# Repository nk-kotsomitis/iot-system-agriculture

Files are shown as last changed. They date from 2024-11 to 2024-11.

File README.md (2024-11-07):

# iot-system-agriculture
*Smart Agriculture IoT System*

The Smart Agriculture IoT System is an end-to-end IoT solution designed to monitor and manage agricultural environments. This repository includes the firmware, hardware, enclosures, and server setup required to deploy the system.



*System Overview*

This system leverages a wireless sensor network in a star topology, using NRF24L01 modules operating at 2.4GHz for communication. The network comprises soil and environmental sensors that gather data and transmit it to a central gateway. The gateway serves as the primary hub, collecting sensor data and communicating with the controllers to make real-time adjustments. For data processing and storage, the gateway connects to an Ubuntu server over WiFi, using the MQTT protocol with RabbitMQ as the message broker. On the server side, InfluxDB is used for time-series data storage and visualization, allowing for easy monitoring of historical and real-time sensor data. 

The gateway is powered by an ATMEGA1284 and connects to the internet via an ESP32 module, utilizing AT commands. The sensors and controllers in the system are based on the ATMEGA328P microcontroller. The environmental sensor is optimized for low-power operation, measuring temperature and humidity with a high-precision SHT40 sensor while also monitoring battery voltage to ensure reliable performance over extended periods. Meanwhile, the soil sensor assesses soil moisture levels using a moisture probe. The controllers are designed for both low and high-power applications, managing devices through relay control. Each controller is equipped with a battery-powered real-time clock (RTC) to maintain accurate time in case of power outages. The high-power controller additionally monitors current consumption using an ACS712 sensor for enhanced energy management.

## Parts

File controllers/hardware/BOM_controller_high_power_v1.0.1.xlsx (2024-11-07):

# | Reference Designators | Quantity | MPN | Manufacturer | Part Description | Value | Package | Remark or Link
1 | U1 | 1 | ATMEGA328P-AU | Microchip Technology / Atmel | 8-bit Microcontrollers - MCU 32KB In-system Flash 20MHz 1.8V-5.5V | ATMEGA328P_TQFP | TQFP-32
2 | U3 | 1 | SPX1117M3-L-3-3/TR | Maxlinear | LDO Voltage Regulators 3.3V 0.8A Positive | 3.3V 0.8A | SOT-223-3+A4:H4
3 | U4 | 1 | HLK-PM01 | Hi-Link | AC-DC 220V to 5V 3W Step-Down Power Supply Module | 220V to 5V | Through Hole
4 | U5 | 1 | - | - | NRF24L01+ 2.4GHz Wireless RF Transceiver Module | - | Plug In Module - 2x4 2.54mm header | Customer Provided
5 | U6 | 1 | MCP79410T-I/SN | Microchip Technology | Real Time Clock I2C GP RTCC 1Kb EE 64B SRAM ID | - | SOIC-8
6 | BH1 | 1 | MY-1220-03 | MYOUNG | Coin Cell Battery Holder CR1220 SMT | - | SMD
7 | K1, K2 | 2 | G2RL-1A-E-ASI DC5 | Omron Electronics | General Purpose Relays 1 form A w/ TV3 5VDC Coil, 16A | Power Relays | Through Hole
8 | U10, U11 | 2 | ACS712ELCTR-20A-T | ALLEGRO MICROSYSTEMS | Linear Current Sensor, Hall Effect, 20A Sensing Current, SOIC-8 | 100mV/A output | SOIC-8
9 | Y1 | 1 | TAXM4M2ILFBET2T | TAE(Zhejiang Abel Elec) | ±30ppm -20℃~70℃ 49SMD 20pF 80Ω 4000000Hz HC-49S/SMD Crystals | 4 MHz | HC-49/S
10 | Y2 | 1 | JFWSH32K25A104C | SHENZHEN JINGFA ELECTRONICS | Radial Cylinder Crystal 32.768KHz ±20ppm 12.5pF 30 KOhm(Max) Radial,3x8mm | 32.768 kHz | OSC-TH Radial 3x8mm
11 | J2, J3 | 2 | PH2.0-4P | CAX | 4-Pin Low-profile PH2.0 Housing Connector | 4 Position | Through Hole
12 | LED | 1 | 204-10SUGC/S400-A5-L | Everlight Elec | Green 525nm Through Hole 3mm Light Emitting Diodes (LED) - Water Clear | 3mm Green - Clear | Through Hole
13 | LED | 1 | ERM 1-1.140 | Bivar | LED Mounting Hardware LED Mount Self Ret Universal LED Black | T-1 3/4 (5mm) | LED Mounts
14 | J5 | 1 | C65114 | BOOMELE(Boom Precision Elec) | 2 2.54mm 6 Straight Header，Breakaway P=2.54mm Pin Headers | 6 Position | Through Hole
15 | J6 | 1 | PZ254V-11-02P | XFCN | 2.54mm Straight 2 1 Header，Breakaway Through Hole,P=2.54mm Pin Headers | 2 Position | Through Hole
16 | J7, J8, J9 | 3 | WJ500V-5.08-3P | Ningbo Kangnex Elec | PCB Screw Terminal Block Connector 5.08mm Pitch 3 Poles Vertical | 3 Position | Through Hole
17 | J10 | 1 | PTF-77 | XFCN | Fuse Holder 5x20 | - | SH22,5A
18 | Q1, Q2 | 2 | MMBT2222A |  | (BJT) NPN 600mA 40V SURFACE MOUNT TRANSISTOR | NPN | SOT23-3
19 | D1, D2 | 2 | 1N4007F (M7) |  | Silicon Rectifier Diode 1A 1000V SMA | 1A 1000V | SMA / DO-214AC
20 | D3, D4 | 2 | 1N4448WS-7-F | Diodes Incorporated | Diodes - General Purpose, Power, Switching Vr/75V Io/250mA T/R | 75 V | SOD-323
21 | C1, C2, C14, C15 | 4 | 0805CG150J500NT |  | Multilayer Ceramic Capacitor MLCC 15pF ±5% 0805 SMD | 15pF | 0805
22 | C3, C4, C5, C16, C18, C20, C21, C22 | 8 | 0805B104M500NT |  | Multilayer Ceramic Capacitor MLCC 100nF ±5% 0805 SMD | 100nF | 0805
23 | C11 | 1 | CL21B225KOFNNNE |  | Multilayer Ceramic Capacitor MLCC 2.2uF X7R ±10% 16V 0805 SMD | 2.2uF | 0805
24 | C10 | 1 | CL21A475KAQNNNE |  | Multilayer Ceramic Capacitor MLCC 4.7uF X5R ±10% 25V 0805 SMD | 4.7uF | 0805
25 | C12 | 1 | GRM21BR61C106KE15L |  | X5R ±10% 16V 10uF 0805 Multilayer Ceramic Capacitors MLCC - SMD/SMT | 10uF | 0805
26 | C13 | 1 | VD1A331ME077000CE0 | Changzhou Huawei Electronics | 6.3mm 330uF 7.7mm 10V 2000hrs 105℃ ±20% -45℃~+105℃ SMD,6.3x7.7mm Aluminum Electrolytic Capacitors - SMD | 330uF | 6.3x7.7 SMD
27 | C17, C19 | 2 | CC0805KRX7R9BB102 |  | 50V 1nF X7R ±10% 0805 Multilayer Ceramic Capacitors MLCC - SMD/SMT | 1nF | 0805
28 | R1, R3, R5, R9, R14, R16 | 6 | RC0805FR-7W10KL |  | Chip Resistor - Surface Mount 10K ±1% 1/4W 0805 | 10K 1/4W | 0805
29 | R2, R4, R11, R12 | 4 | 0805W8J1001T5E |  | Chip Resistor - Surface Mount 1K ±5% 1/8W 0805 | 1K | 0805
30 | R13, R15 | 2 | 0805W8J2001T5E |  | Chip Resistor - Surface Mount 2K ±5% 1/8W 0805 | 2K | 0805
31 | R6, R7, R8, R10 | 4 | 0805W8J0472T5E |  | Chip Resistor - Surface Mount 4.7K ±5% 1/8W 0805 | 4K7 | 0805
 | Off-board components
32 | - | 1 | CMC_313_GTP | Visual Communications Company (VCC) | LED Lenses Green Diffused 5mm CMC313GTP | Green | -
33 | - | 2 | TC013-N11ASKKUGXX | Well Buying | Tactile Switches TACTILE/JOG SWITCH SPST50mA 12VDC180gf | Illuminated | -
34 | - | 2 | - |  | PH2.0 PH 2.0 4pin PH-4p connector with cable 100mm wire 24AWG | PH-4p 100mm 24AWG | -
35 | - | 1 | 0218015.MXP |  | 250V 15A Glass Tube Fuse Slow Blow,5x20mm Fuses | 15 A | -

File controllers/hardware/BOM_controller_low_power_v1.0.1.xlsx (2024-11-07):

# | Reference Designators | Quantity | MPN | Manufacturer | Part Description | Value | Package | Remark or Link
1 | U1 | 1 | ATMEGA328P-AU | Microchip Technology / Atmel | 8-bit Microcontrollers - MCU 32KB In-system Flash 20MHz 1.8V-5.5V | ATMEGA328P_TQFP | TQFP-32
2 | U3 | 1 | SPX1117M3-L-3-3/TR | Maxlinear | LDO Voltage Regulators 3.3V 0.8A Positive | 3.3 V | SOT-223-3
3 | U5 | 1 | - | - | NRF24L01+ 2.4GHz Wireless RF Transceiver Module | - | Plug In Module - 2x4 2.54mm header | Customer Provided
4 | U6 | 1 | MCP79410T-I/SN | Microchip Technology | Real Time Clock I2C GP RTCC 1Kb EE 64B SRAM ID | - | SOIC-8
5 | BH1 | 1 | MY-1220-03 | MYOUNG | Coin Cell Battery Holder CR1220 SMT | - | SMD
6 | K1, K2 | 2 | G2RL-1A-E-ASI DC5 | Omron Electronics | General Purpose Relays 1 form A w/ TV3 5VDC Coil, 16A | Power Relays | Through Hole
7 | Y1 | 1 | TAXM4M2ILFBET2T | TAE(Zhejiang Abel Elec) | ±30ppm -20℃~70℃ 49SMD 20pF 80Ω 4000000Hz HC-49S/SMD Crystals | 4 MHz | HC-49/S
8 | Y2 | 1 | JFWSH32K25A104C | SHENZHEN JINGFA ELECTRONICS | Radial Cylinder Crystal 32.768KHz ±20ppm 12.5pF 30 KOhm(Max) Radial,3x8mm | 32.768 kHz | OSC-TH Radial 3x8mm
9 | J2, J3 | 2 | PH2.0-4P | CAX | 4-Pin Low-profile PH2.0 Housing Connector | 4 Position | Through Hole
10 | LED | 1 | 204-10SUGC/S400-A5-L | Everlight Elec | Green 525nm Through Hole 3mm Light Emitting Diodes (LED) - Water Clear | 3mm Green - Clear | Through Hole
11 | LED | 1 | ERM 1-955 | Bivar | LED Mounting Hardware LED Mount Self Ret Universal LED Black | T-1 3/4 (5mm) | -
12 | J5 | 1 | C65114 | BOOMELE(Boom Precision Elec) | 2 2.54mm 6 Straight Header，Breakaway P=2.54mm Pin Headers | 6 Position | Through Hole
13 | J6 | 1 | PZ254V-11-02P | XFCN | 2.54mm Straight 2 1 Header，Breakaway Through Hole,P=2.54mm Pin Headers | 2 Position | Through Hole
14 | J7, J8 | 2 | WJ2EDGRC-5.08-4P | Ningbo Kangnex Elec | Pluggable Terminal Blocks 4Pins Pitch 5.08 Right Angle | 4 Position | Through Hole
15 | Q1, Q2 | 2 | MMBT2222A |  | (BJT) NPN 600mA 40V SURFACE MOUNT TRANSISTOR | NPN | SOT23-3
16 | D1, D2 | 2 | 1N4007F (M7) |  | Silicon Rectifier Diode 1A 1000V SMA | 50 V | SMA / DO-214AC
17 | C1, C2, C14, C15 | 4 | 0805CG150J500NT |  | Multilayer Ceramic Capacitor MLCC 15pF ±5% 0805 SMD | 15pF | 0805
18 | C3, C4, C5, C16 | 4 | 0805B104M500NT |  | Multilayer Ceramic Capacitor MLCC 100nF ±5% 0805 SMD | 100nF | 0805
19 | C11 | 1 | CL21B225KOFNNNE |  | Multilayer Ceramic Capacitor MLCC 2.2uF X7R ±10% 16V 0805 SMD | 2.2uF | 0805
20 | C10 | 1 | CL21A475KAQNNNE |  | Multilayer Ceramic Capacitor MLCC 4.7uF X5R ±10% 25V 0805 SMD | 4.7uF | 0805
21 | C12 | 1 | GRM21BR61C106KE15L |  | X5R ±10% 16V 10uF 0805 Multilayer Ceramic Capacitors MLCC - SMD/SMT | 10uF | 0805
22 | C13 | 1 | VD1A331ME077000CE0 | Changzhou Huawei Electronics | 6.3mm 330uF 7.7mm 10V 2000hrs 105℃ ±20% -45℃~+105℃ SMD,6.3x7.7mm Aluminum Electrolytic Capacitors - SMD | 330uF | 6.3x7.7 SMD
23 | R1, R3, R5, R9 | 4 | RC0805FR-7W10KL |  | Chip Resistor - Surface Mount 10K ±1% 1/4W 0805 | 10K 1/4W | 0805
24 | R2, R4, R11, R12 | 4 | 0805W8J1001T5E |  | Chip Resistor - Surface Mount 1K ±5% 1/8W 0805 | 1K | 0805
25 | R6, R7, R8, R10 | 4 | 0805W8J0472T5E |  | Chip Resistor - Surface Mount 4.7K ±5% 1/8W 0805 | 4K7 | 0805
 | Off-board components
26 | - | 1 | CMC_313_GTP | Visual Communications Company (VCC) | LED Lenses Green Diffused 5mm CMC313GTP | Green | -
27 | - | 2 | TC013-N11ASKKUGXX | Well Buying | Tactile Switches TACTILE/JOG SWITCH SPST50mA 12VDC180gf | Illuminated | -
28 | - | 2 | - |  | PH2.0 PH 2.0 4pin PH-4p connector with cable 100mm wire 24AWG | PH-4p 100mm 24AWG | -
29 |  | 2 | WJ2EDGK-5.08-4P | Ningbo Kangnex Elec | Pluggable Terminal Blocks Screw Connector 4Pins Pitch 5.08 | 4 Position | -

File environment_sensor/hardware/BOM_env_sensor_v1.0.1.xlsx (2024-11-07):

# | Reference Designators | Quantity | MPN | Manufacturer | Part Description | Value | Package | Remark or Link
1 | U1 | 1 | ATMEGA328P-AU | Microchip Technology / Atmel | 8-bit Microcontrollers - MCU 32KB In-system Flash 20MHz 1.8V-5.5V | - | TQFP-32
2 | U2 | 1 | - | NRF24L01+ 2.4GHz Wireless RF Transceiver Module | - | Plug In Module - 2x4 2.54mm header | Customer Provided
3 | U3 | 1 | SHT40-AD1B-R2 | Sensirion | Board Mount Humidity Sensors RH/ T Sensor | SHT40-AD1B-R2 | DFN-4
4 | U4 | 1 | USEQGSEAC82180 | KEMET | Air Quality Sensors Gas Detector Sensor Digital SMD CO2 | Carbon Dioxide (CO2) | SMD/SMT
5 | U5 | 1 | TCA9406DCTR | Texas Instruments | Translation - Voltage Levels Dual Bidirec 1MHz Vltg Lev-Trans | Translation - Voltage Levels | SM-8
6 | U6 | 1 | TPS60205DGSR | Texas Instruments | Switching Voltage Regulators Regulated 3.3-V Charge Pump | 3.3 V | MSOP-10
7 | Y1 | 1 | TAXM4M2ILFBET2T | TAE(Zhejiang Abel Elec) | ±30ppm -20℃~70℃ 49SMD 20pF 80Ω 4000000Hz HC-49S/SMD Crystals | 4 MHz | HC-49/S
8 | Q1, Q2 | 2 | SSM3J328R,LF | Toshiba | MOSFET P-Ch Sm Sig FET Id -6A -20V -8VGSS | P-channel | SOT-23F-3
9 | D1 | 1 | SBAT54CLT1G | ON Semiconductor | Schottky Diodes & Rectifiers SS DUAL COMMON CATHODE | Si | SOT-23
11 | J1 | 1 | PH2.0-4P | CAX | 4-Pin Low-profile PH2.0 Housing Connector | 4 Position | Through Hole
12 | J2 | 1 | C65114 | BOOMELE(Boom Precision Elec) | 2 2.54mm 6 Straight Header，Breakaway P=2.54mm Pin Headers | 6 Position | Through Hole
13 | J3 | 1 | PZ254V-11-02P | XFCN | 2.54mm Straight 2 1 Header，Breakaway Through Hole,P=2.54mm Pin Headers | 2 Position | Through Hole
14 | J4 | 1 | 2462 | Keystone Electronics | Cylindrical Battery Contacts, Clips, Holders & Springs 2 CELL AA PC HOLDER | AA 2 Battery | Through Hole
15 | J5 | 1 | ZW-02-20-F-D-800-079 | Samtec | Board to Board & Mezzanine Connectors .100" Flex Stack, Flexible Board Stacker, Custom Tail | 4 Position | Through Hole
16 | CBAT | 1 | VD1A331ME077000CE0 | Changzhou Huawei Electronics | 6.3mm 330uF 7.7mm 10V 2000hrs 105℃ ±20% -45℃~+105℃ SMD,6.3x7.7mm Aluminum Electrolytic Capacitors - SMD | 330uF | 6.3x7.7 SMD
18 | C1, C2 | 2 | 0805CG150J500NT |  | Multilayer Ceramic Capacitor MLCC 15pF ±5% 0805 SMD | 15pF | 0805
19 | C9 | 1 | TCC0805X7R224K500DT |  | 50V 220nF X7R ±10% 0805 Multilayer Ceramic Capacitors MLCC - SMD/SMT | 220nF | 0805
20 | C3, C4, C5, C6, C8, C14, C15, C17 | 8 | 0805B104M500NT |  | Multilayer Ceramic Capacitor MLCC 100nF ±5% 0805 SMD | 100nF | 0805
21 | C11, C12 | 2 | CL21B105KOFNNNE |  | Multilayer Ceramic Capacitor MLCC 1uF X7R ±10% 16V 0805 SMD | 1uF | 0805
22 | C10, C13 | 2 | CL21B225KOFNNNE |  | Multilayer Ceramic Capacitor MLCC 2.2uF X7R ±10% 16V 0805 SMD | 2.2uF | 0805
23 | C7 | 1 | GRM21BR61C106KE15L |  | X5R ±10% 16V 10uF 0805 Multilayer Ceramic Capacitors MLCC - SMD/SMT | 10uF | 0805
24 | C16 | 1 | CL21A475KAQNNNE |  | 25V 4.7uF X5R ±10% 0805 Multilayer Ceramic Capacitors MLCC - SMD/SMT | 4.7uF | 0805
25 | R1, R6, R7, R8, R9 | 5 | RC0805FR-7W10KL |  | Chip Resistor - Surface Mount 10K ±1% 1/4W 0805 | 10K 1/4W | 0805
26 | R2 | 1 | 0805W8J0105T5E |  | Chip Resistor - Surface Mount 1M ±5% 1/8W 0805 | 1M | 0805
27 | R3 | 1 | 0805W8J0474T5E |  | Chip Resistor - Surface Mount 470K ±5% 1/8W 0805 | 470K | 0805
28 | R4, R5 | 2 | 0805W8J1001T5E |  | Chip Resistor - Surface Mount 1K ±5% 1/8W 0805 | 1K | 0805
 | Off-board components
29 | - | 1 | TC013-N11ASKKUGXX | Well Buying | Tactile Switches TACTILE/JOG SWITCH SPST50mA 12VDC180gf | Illuminated | -
30 | - | 1 | - | - | PH2.0 PH 2.0 4pin PH-4p connector with cable 100mm wire 24AWG | PH-4p 100mm 24AWG | -

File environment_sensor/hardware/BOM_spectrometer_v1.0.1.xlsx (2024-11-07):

# | Reference Designators | Quantity | MPN | Manufacturer | Part Description | Value | Package
1 | U1 | 1 | AS72651-BLGT | ams | Ambient Light Sensors AS72651-BLGT LGA20 LF T&RDP | 600 nm to 870 nm | LGA-20
2 | U2 | 1 | AS72652-BLGT | ams | Ambient Light Sensors AS72652-BLGT LGA20 LF T&RDP | - | LGA-20
3 | U3 | 1 | AS72653-BLGT | ams | Ambient Light Sensors AS72653-BLGT LGA20 LF T&RDP | - | LGA-20
4 | U4 | 1 | AT25SF041B-SSHB-B | Adesto Technologies | NOR Flash 4 Mbit, 3.0V (2.7V to 3.6V), -40C to 85C, SOIC-N 150mil (Tube), Single, Dual, Quad SPI NOR flash | 4 Mbit | SOIC-8 Narrow
5 | J2 | 1 | PZ254V-12-10P | XFCN | 2 2.54mm 10 Straight Header，Breakaway Through Hole,P=2.54mm Pin Headers ROHS | 10 Position | Through Hole
6 | R1, R2 | 2 | 0805W8J0472T5E |  | Chip Resistor - Surface Mount 4.7K ±5% 1/8W 0805 | 4K7 | 0805
7 | R3, R4, R5, R6, R7 | 5 | RC0805FR-7W10KL |  | Chip Resistor - Surface Mount 10K ±1% 1/4W 0805 | 10K | 0805
8 | C1, C3, C5 | 3 | GRM21BR61C106KE15L |  | X5R ±10% 16V 10uF 0805 Multilayer Ceramic Capacitors MLCC - SMD/SMT | 10uF | 0805
9 | C2, C4, C6 | 3 | 0805B104M500NT |  | Multilayer Ceramic Capacitor MLCC 100nF ±5% 0805 SMD | 100nF | 0805
10 | C7 | 1 | UMK212B7105KG-T |  | X7R ±10% 50V 1uF 0805 Multilayer Ceramic Capacitors MLCC - SMD/SMT | 1uF | 0805

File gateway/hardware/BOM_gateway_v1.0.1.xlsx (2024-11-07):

# | Reference Designators | Quantity | MPN | Manufacturer | Part Description | Value | Package | Remark or Link
1 | U1 | 1 | ATMEGA1284-AU | Microchip Technology / Atmel | 8-bit Microcontrollers - MCU AVR 128KB FLSH 4KB EE16KB SRAM-20 MHz | - | TQFP-44
2 | U2 | 1 | SPX1117M3-L-3-3/TR | Maxlinear | LDO Voltage Regulators 3.3V 0.8A Positive | 3.3V 0.8A | SOT-223-3
3 | U4 | 1 | - | - | NRF24L01+ 2.4GHz Wireless RF Transceiver Module | - | Plug In Module - 2x4 2.54mm header | Customer Provided
4 | U5 | 1 | ESP-WROOM-02D(M1102H1600PH3Q0) | Espressif Systems | WiFi Modules (802.11) SMD Module, ESP8266EX, 16Mbits SPI flash, UART Mode, PCB antenna | - | SMD module
5 | U6 | 1 | MCP79410T-I/SN | Microchip Technology | Real Time Clock I2C GP RTCC 1Kb EE 64B SRAM ID | - | SOIC-8
6 | BH1 | 1 | MY-1220-03 | MYOUNG | Coin Cell Battery Holder CR1220 SMT | - | SMD
7 | Y1 | 1 | TXM16M0004322KBCDO00T | TAE(Zhejiang Abel Elec) | ±10ppm 16000000Hz -40℃~85℃ 18pF SMD Passive Crystal Oscillator 35Ω SMD3225-4P Crystals | 16 MHz | SMD3225-4P
8 | Y2 | 1 | JFWSH32K25A104C | SHENZHEN JINGFA ELECTRONICS | Radial Cylinder Crystal 32.768KHz ±20ppm 12.5pF 30 KOhm(Max) Radial,3x8mm | 32.768 kHz | OSC-TH Radial 3x8mm
9 | J1 | 1 | PH2.0-4P | CAX | 4-Pin Low-profile PH2.0 Housing Connector | 4 Position | Through Hole
10 | LED1, LED2, LED3 | 3 | 204-10SUGC/S400-A5-L | Everlight Elec | Green 525nm Through Hole 3mm Light Emitting Diodes (LED) - Water Clear | 3mm Green - Clear | Through Hole
11 | LED1, LED2, LED3 | 3 | ERM 1-955 | Bivar | LED Mounting Hardware LED Mount Self Ret Universal LED Black | T-1 3/4 (5mm) | - | Led Spacer
12 | J6 | 1 | C65114 | BOOMELE(Boom Precision Elec) | 2 2.54mm 6 Straight Header，Breakaway P=2.54mm Pin Headers | 6 Position | Through Hole
13 | J7 | 1 | PZ254V-11-02P | XFCN | 2.54mm Straight 2 1 Header，Breakaway Through Hole,P=2.54mm Pin Headers | 2 Position | Through Hole
14 | J8 | 1 | C49257 | BOOMELE(Boom Precision Elec) | 3 2.54mm Straight 1 Header，Breakaway Through Hole Pin Headers | 3 Position | Through Hole
15 | S2, S3 | 2 | TS-1096S-A2B2-C1D2 | Yuandi | SPST Vertical Tactile Switch 3X6X5.0mm SMT | - | SMD
16 | C15, C16 | 2 | 0805CG150J500NT |  | Multilayer Ceramic Capacitor MLCC 15pF ±5% 0805 SMD | 15pF | 0805
17 | C1, C2 | 2 | 0805CG270J500NT |  | Multilayer Ceramic Capacitor MLCC 27pF ±5% 0805 SMD | 27pF | 0805
18 | C3, C4, C5, C6, C7, C13, C14, C17 | 8 | 0805B104M500NT |  | Multilayer Ceramic Capacitor MLCC 100nF ±5% 0805 SMD | 100nF | 0805
19 | C9 | 1 | CL21B225KOFNNNE |  | Multilayer Ceramic Capacitor MLCC 2.2uF X7R ±10% 16V 0805 SMD | 2.2uF | 0805
20 | C8 | 1 | CL21A475KAQNNNE |  | Multilayer Ceramic Capacitor MLCC 4.7uF X5R ±10% 25V 0805 SMD | 4.7uF | 0805
21 | C10, C12 | 2 | GRM21BR61C106KE15L |  | X5R ±10% 16V 10uF 0805 Multilayer Ceramic Capacitors MLCC - SMD/SMT | 10uF | 0805
22 | C11 | 1 | VD1A331ME077000CE0 | Changzhou Huawei Electronics | 6.3mm 330uF 7.7mm 10V 2000hrs 105℃ ±20% -45℃~+105℃ SMD,6.3x7.7mm Aluminum Electrolytic Capacitors - SMD | 330uF | 6.3x7.7 SMD
23 | R1, R2, R11, R12, R13, R16, R17, R18 | 8 | 0805W8J1002T5E |  | Chip Resistor - Surface Mount 10K ±5% 1/8W 0805 | 10K | 0805
24 | R14 | 1 | 0805W8J1001T5E |  | Chip Resistor - Surface Mount 1K ±5% 1/8W 0805 | 1K | 0805
25 | R15 | 1 | 0805W8J2001T5E |  | Chip Resistor - Surface Mount 2K ±5% 1/8W 0805 | 2K | 0805
26 | R4, R5, R6, R7, R8, R9, R10, R19 | 8 | 0805W8J0472T5E |  | Chip Resistor - Surface Mount 4.7K ±5% 1/8W 0805 | 4K7 | 0805
 | Off-board components
27 | - | 1 | TC013-N11ASKKUGXX | Well Buying | Tactile Switches TACTILE/JOG SWITCH SPST50mA 12VDC180gf | Illuminated | -
28 | - | 3 | CMC_313_GTP | Visual Communications Company (VCC) | LED Lenses Green Diffused 5mm CMC313GTP | Green | -
29 | - | 1 | - | - | PH2.0 PH 2.0 4pin PH-4p connector with cable 100mm wire 24AWG | PH-4p 100mm 24AWG | -

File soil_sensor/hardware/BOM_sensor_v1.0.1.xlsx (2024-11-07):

# | Reference Designators | Quantity | MPN | Manufacturer | Part Description | Value | Package | Remark or Link
1 | U1 | 1 | ATMEGA328P-AU | Microchip Technology / Atmel | 8-bit Microcontrollers - MCU 32KB In-system Flash 20MHz 1.8V-5.5V | ATMEGA328P_TQFP | TQFP-32
2 | U2 | 1 | - | - | NRF24L01+ 2.4GHz Wireless RF Transceiver Module | - | Plug In Module - 2x4 2.54mm header | Customer Provided
3 | Y1 | 1 | TAXM4M2ILFBET2T | TAE(Zhejiang Abel Elec) | ±30ppm -20℃~70℃ 49SMD 20pF 80Ω 4000000Hz HC-49S/SMD Crystals | 4 MHz | HC-49/S
4 | Q1 | 1 | SSM3J328R,LF | Toshiba | MOSFET P-Ch Sm Sig FET Id -6A -20V -8VGSS |  | SOT-23F-3
5 | D1 | 1 | SBAT54CLT1G | ON Semiconductor | Schottky Diodes & Rectifiers SS DUAL COMMON CATHODE | Schottky Diodes | SOT-23
6 | D2, D3, D4, D5 | 4 | 1SS384TE85LF | 1SS384TE85LF | Schottky Diodes & Rectifiers 0.1A 10V Schottky Small Sig Diode | Schottky Diodes | SOT-343-4
7 | J1 | 1 | PH2.0-4P | CAX | 4-Pin Low-profile PH2.0 Housing Connector | 4 Position | Through Hole
8 | J2 | 1 | C65114 | BOOMELE(Boom Precision Elec) | 2 2.54mm 6 Straight Header，Breakaway P=2.54mm Pin Headers | 6 Position | Through Hole
9 | J3 | 1 | PZ254V-11-02P | XFCN | 2.54mm Straight 2 1 Header，Breakaway Through Hole,P=2.54mm Pin Headers | 2 Position | Through Hole
10 | J4 | 1 | 2462 | Keystone Electronics | Cylindrical Battery Contacts, Clips, Holders & Springs 2 CELL AA PC HOLDER | AA 2 Battery | Through Hole
11 | J5, J6, J7, J8 | 4 | STX-3120-3B | Kycon | Phone Connectors 3.5mm PCB STEREO BLK 3P ALL PLASTIC | 3.5 mm, 1/8 in | Through Hole
12 | CBAT | 1 | VD1A331ME077000CE0 | Changzhou Huawei Electronics | 6.3mm 330uF 7.7mm 10V 2000hrs 105℃ ±20% -45℃~+105℃ SMD,6.3x7.7mm Aluminum Electrolytic Capacitors - SMD | 330uF | 6.3x7.7 SMD
13 | C1, C2 | 2 | 0805CG150J500NT |  | Multilayer Ceramic Capacitor MLCC 15pF ±5% 0805 SMD | 15pF | 0805
14 | C3, C4, C5, C6 | 4 | 0805B104M500NT |  | Multilayer Ceramic Capacitor MLCC 100nF ±5% 0805 SMD | 100nF | 0805
15 | C8, C9, C10, C11 | 4 | UMK212B7105KG-T |  | X7R ±10% 50V 1uF 0805 Multilayer Ceramic Capacitors MLCC - SMD/SMT | 1uF | 0805
16 | C7 | 1 | GRM21BR61C106KE15L |  | X5R ±10% 16V 10uF 0805 Multilayer Ceramic Capacitors MLCC - SMD/SMT | 10uF | 0805
17 | R1, R6 | 2 | RC0805FR-7W10KL |  | Chip Resistor - Surface Mount 10K ±1% 1/4W 0805 | 10K 1/4W | 0805
18 | R2 | 1 | 0805W8J0105T5E |  | Chip Resistor - Surface Mount 1M ±5% 1/8W 0805 | 1M | 0805
19 | R3 | 1 | 0805W8J0474T5E |  | Chip Resistor - Surface Mount 470K ±5% 1/8W 0805 | 470K | 0805
20 | R4, R5, R7, R9, R11, R13 | 6 | 0805W8J1001T5E |  | Chip Resistor - Surface Mount 1K ±5% 1/8W 0805 | 1K | 0805
21 | R8, R10, R12, R14 | 4 | 0805W8J0564T5E |  | Chip Resistor - Surface Mount 560K ±5% 1/8W 0805 | 560K | 0805
 | Off-board components
22 | - | 4 | 172-1283 | Kobiconn | Audio Cables / Video Cables / RCA Cables 3.5 MONO PL-S/T 36" | 3.5 mm Mono Plug | -
23 | - | 1 | TC013-N11ASKKUGXX | Well Buying | Tactile Switches TACTILE/JOG SWITCH SPST50mA 12VDC180gf | Illuminated | -
24 | - | 1 | - | - | PH2.0 PH 2.0 4pin PH-4p connector with cable 100mm wire 24AWG | PH-4p 100mm 24AWG | -

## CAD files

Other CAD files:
controllers/mechanical/WP13-18-5 G_controller.dwg
environment_sensor/mechanical/PMF-12HAB_environment_sensor.dwg
gateway/mechanical/WP10-10-4 G_gateway.dwg
soil_sensor/mechanical/WP10-10-4G_soil_sensor.dwg
environment_sensor/mechanical/WP10-10-4G_environment_sensor.dwg

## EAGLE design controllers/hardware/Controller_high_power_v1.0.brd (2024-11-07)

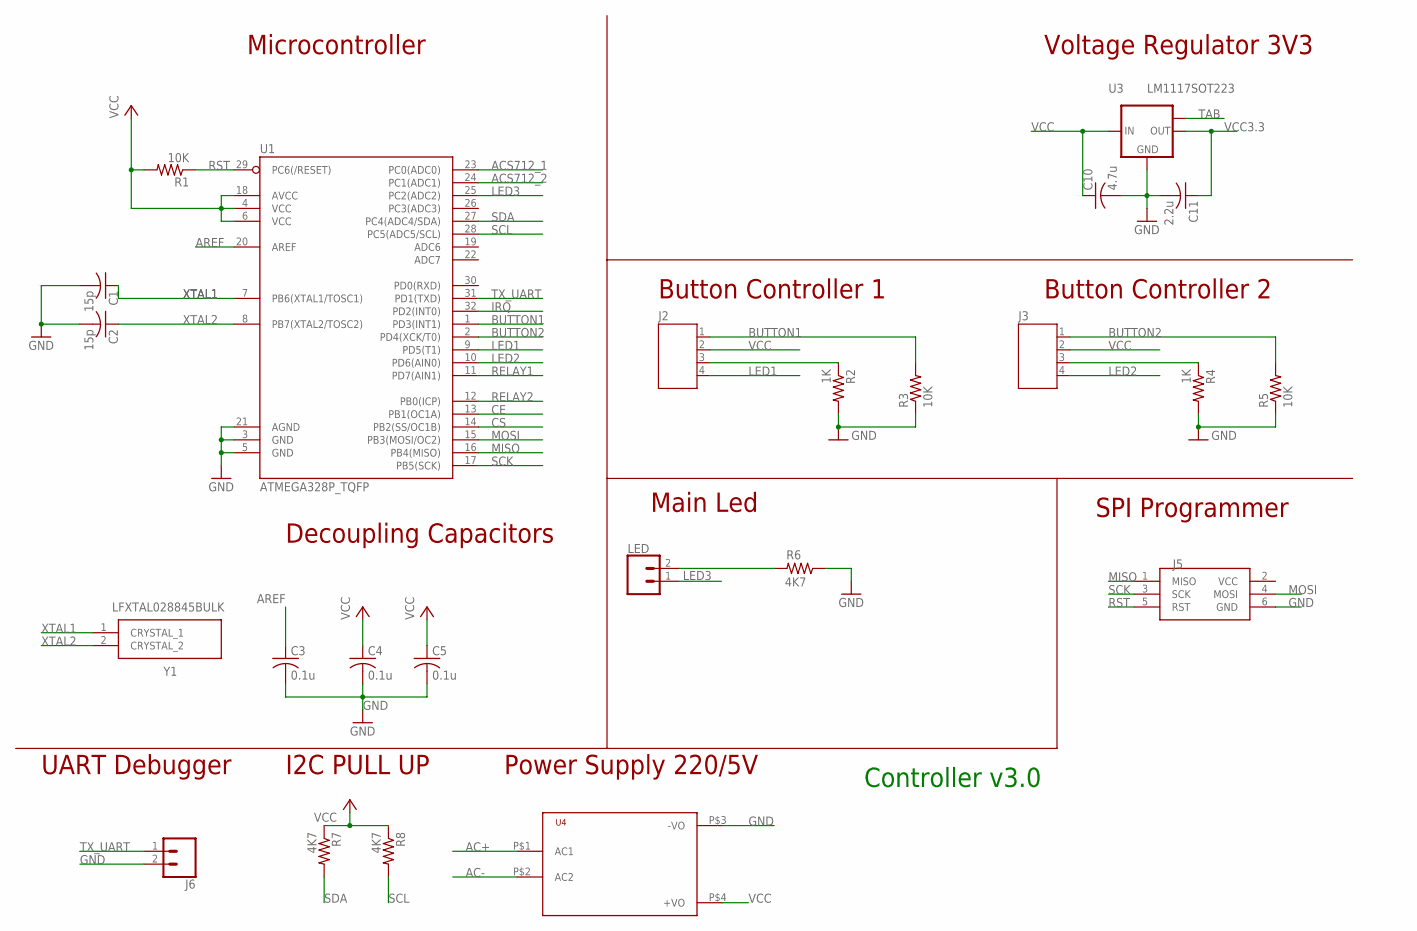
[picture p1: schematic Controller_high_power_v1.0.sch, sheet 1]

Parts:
C1, C2: 15p; SMD-0805
C3, C4, C5: 0.1u; SMD-0805
C10: 4.7u; SMD-0805
C11: 2.2u; SMD-0805
J2, J3: JST-PH4
J5: ISP; AVRISP
J6: CONN_02; 1X02
LED: CONN_02; 1X02
R1, R3, R5: 10K; SMD-0805
R2, R4: 1K; SMD-0805
R6, R7, R8: 4K7; SMD-0805
U1: ATMEGA328P_TQFP; TQFP32-08
U3: LM1117SOT223; SOT223
U4: HKLPM01
Y1: LFXTAL028845BULK

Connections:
AC+: U4.P$1 (AC1); also elsewhere on the board
AC-: U4.P$2 (AC2); also elsewhere on the board
ACS712_1: U1.23 (PC0(ADC0)); also elsewhere on the board
ACS712_2: U1.24 (PC1(ADC1)); also elsewhere on the board
AREF: C3.1, U1.20 (AREF)
BUTTON1: J2.1, R3.2, U1.1 (PD3(INT1))
BUTTON2: J3.1, R5.2, U1.2 (PD4(XCK/T0))
CE: U1.13 (PB1(OC1A)); also elsewhere on the board
CS: U1.14 (PB2(SS/OC1B)); also elsewhere on the board
GND: C1.2, C2.2, C3.2, C4.2, C5.2, C10.2, C11.2, J5.6 (GND), J6.2, R2.2, R3.1, R4.2, R5.1, R6.1, U1.3 (GND), U1.5 (GND), U1.21 (AGND), U3.1 (GND), U4.P$3 (-VO); also elsewhere on the board
IRQ: U1.32 (PD2(INT0)); also elsewhere on the board
LED1: J2.4, U1.9 (PD5(T1))
LED2: J3.4, U1.10 (PD6(AIN0))
LED3: LED.1, U1.25 (PC2(ADC2))
MISO: J5.1 (MISO), U1.16 (PB4(MISO)); also elsewhere on the board
MOSI: J5.4 (MOSI), U1.15 (PB3(MOSI/OC2)); also elsewhere on the board
unnamed: LED.2, R6.2
unnamed: J2.3, R2.1
unnamed: J3.3, R4.1
RELAY1: U1.11 (PD7(AIN1)); also elsewhere on the board
RELAY2: U1.12 (PB0(ICP)); also elsewhere on the board
RST: J5.5 (RST), R1.1, U1.29 (PC6(/RESET))
SCK: J5.3 (SCK), U1.17 (PB5(SCK)); also elsewhere on the board
SCL: R8.2, U1.28 (PC5(ADC5/SCL)); also elsewhere on the board
SDA: R7.2, U1.27 (PC4(ADC4/SDA)); also elsewhere on the board
TAB: U3.TAB (OUT1)
TX_UART: J6.1, U1.31 (PD1(TXD))
VCC: C4.1, C5.1, C10.1, J2.2, J3.2, J5.2 (VCC), R1.2, R7.1, R8.1, U1.4 (VCC), U1.6 (VCC), U1.18 (AVCC), U3.3 (IN), U4.P$4 (+VO); also elsewhere on the board
VCC3.3: C11.1, U3.2 (OUT); also elsewhere on the board
XTAL1: C1.1, U1.7 (PB6(XTAL1/TOSC1)), Y1.1 (CRYSTAL_1)
XTAL2: C2.1, U1.8 (PB7(XTAL2/TOSC2)), Y1.2 (CRYSTAL_2)

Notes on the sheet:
Controller v3.0
Decoupling Capacitors
Voltage Regulator 3V3
Microcontroller
UART Debugger
SPI Programmer
I2C PULL UP
Main Led
Button Controller 1
Power Supply 220/5V
Button Controller 2

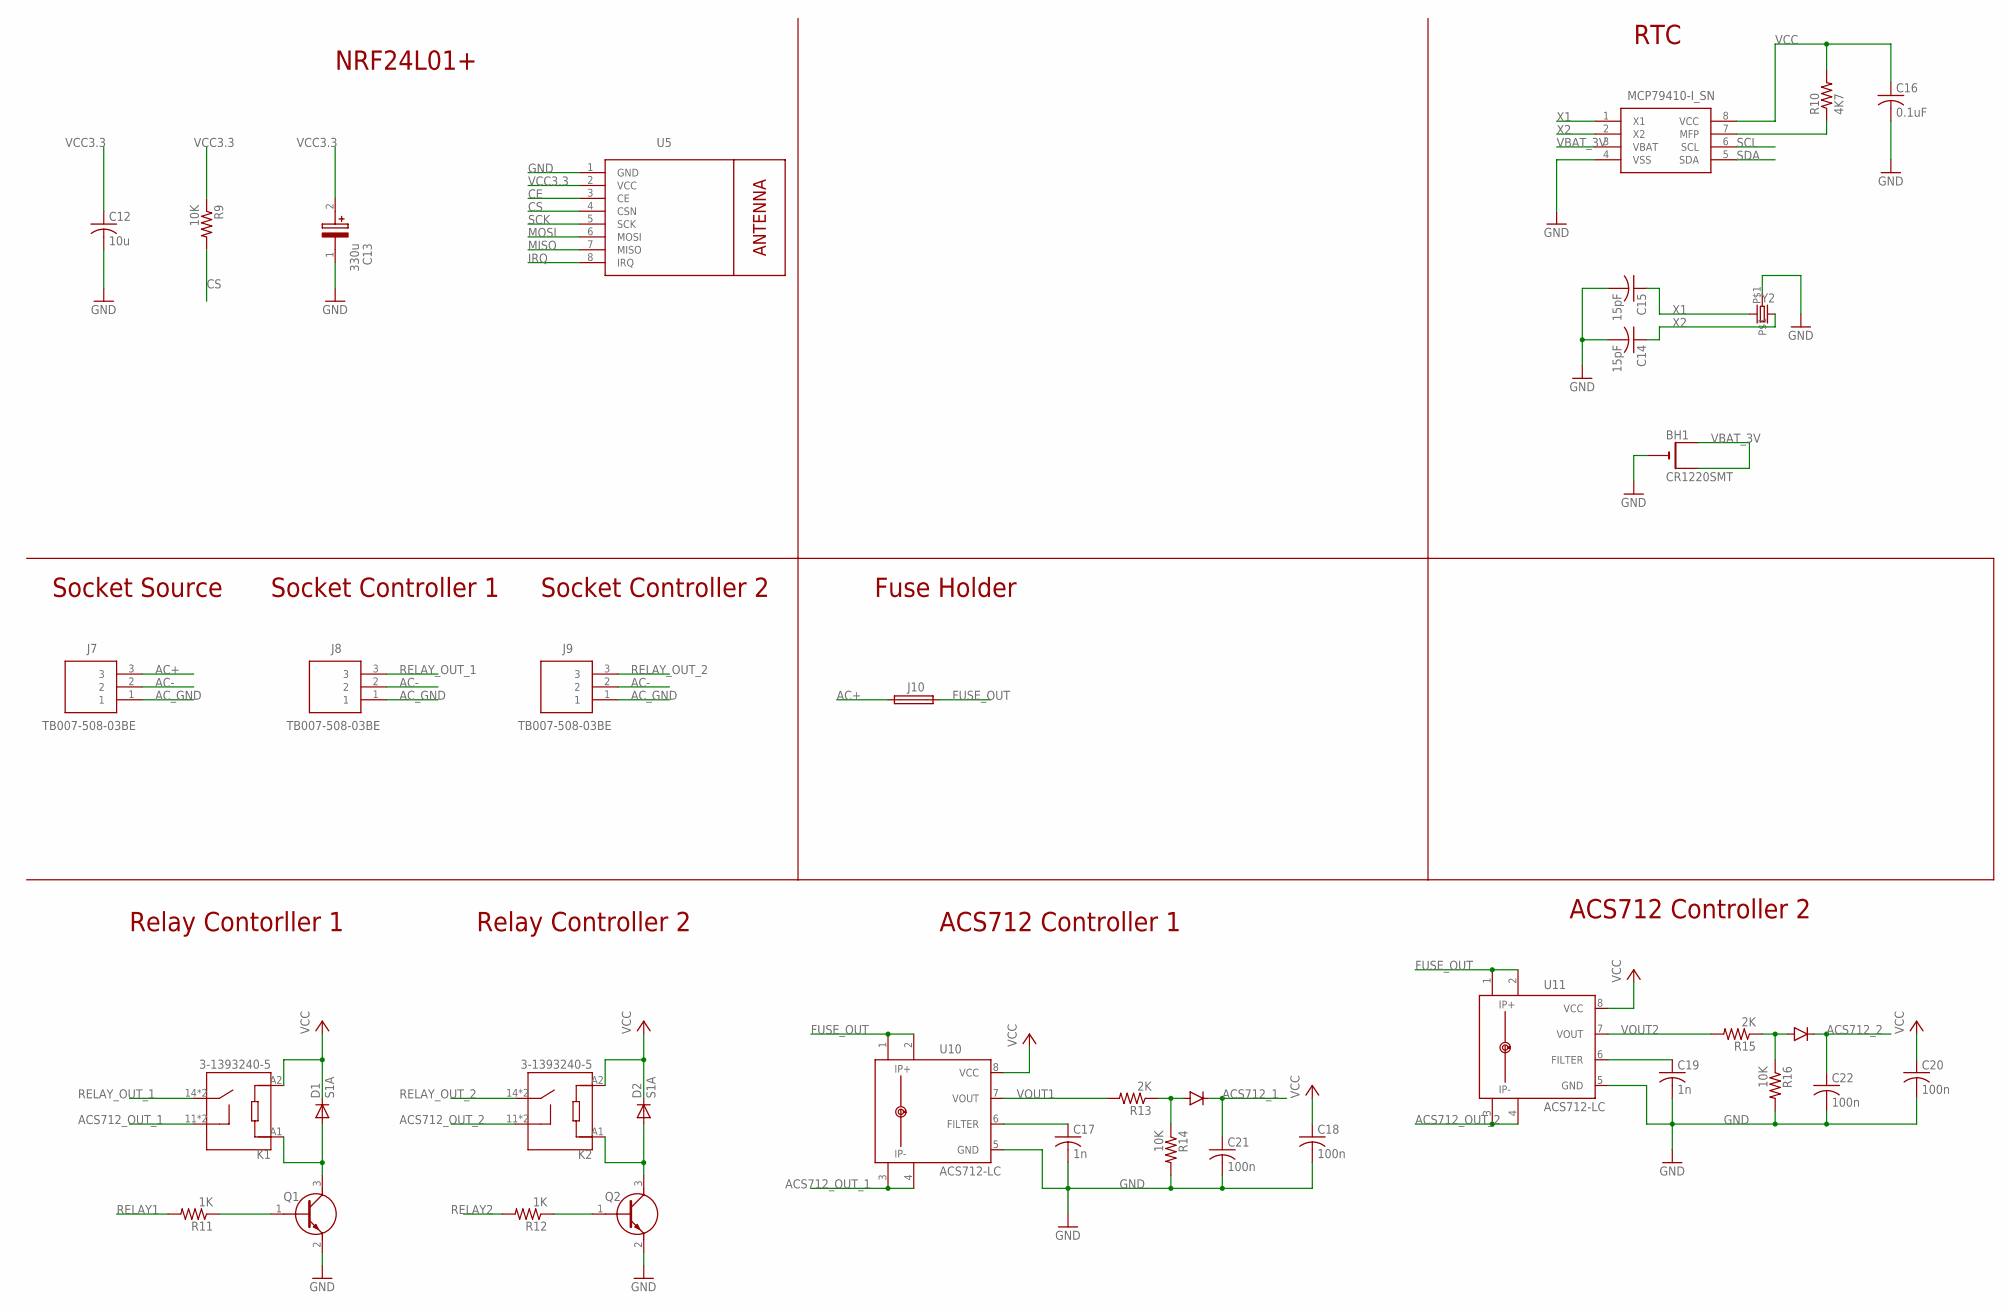
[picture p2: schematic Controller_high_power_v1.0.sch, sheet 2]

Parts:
BH1: CR1220SMT; CR1220-SMD
C12: 10u; SMD-0805
C13: 330u; SMD_LYTIC_D8
C14, C15: 15pF; SMD-0805
C16: 0.1uF; SMD-0805
C17, C19: 1n; SMD-0805
C18, C20, C21, C22: 100n; SMD-0805
D1, D2: S1A; DO214AC
D3, D4: DIODE; SOD-323
J7, J8, J9: TB007-508-03BE; TB00750803BE
J10: SH22,5A
K1, K2: 3-1393240-5; TE_3-1393240-5
Q1, Q2: MMBT2222A-TP; SI2305TP
R9, R14, R16: 10K; SMD-0805
R10: 4K7; SMD-0805
R11, R12: 1K; SMD-0805
R13, R15: 2K; SMD-0805
U5: WIRELESS-NRF24L01
U6: MCP79410-I_SN; SOIC127P600X175-8N
U10, U11: ACS712-LC; SOIC8
Y2: CRYSTALTC26H; TC26H

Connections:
AC+: J7.3, J10.1; also elsewhere on the board
AC-: J7.2, J8.2, J9.2; also elsewhere on the board
ACS712_1: C21.1, D3.C; also elsewhere on the board
ACS712_2: C22.1, D4.C; also elsewhere on the board
ACS712_OUT_1: K1.11, K1.11-1 (11), U10.3 (IP-), U10.4 (IP-1)
ACS712_OUT_2: K2.11, K2.11-1 (11), U11.3 (IP-), U11.4 (IP-1)
AC_GND: J7.1, J8.1, J9.1
CE: U5.3 (CE); also elsewhere on the board
CS: R9.2, U5.4 (CSN); also elsewhere on the board
FUSE_OUT: J10.2, U10.1 (IP+), U10.2 (IP+1), U11.1 (IP+), U11.2 (IP+1)
GND: BH1.-, C12.2, C13.1, C14.2, C15.2, C16.2, C17.2, C18.2, C19.2, C20.2, C21.2, C22.2, Q1.2 (E), Q2.2 (E), R14.2, R16.2, U5.1 (GND), U6.4 (VSS), U10.5 (GND), U11.5 (GND), Y2.P$1; also elsewhere on the board
IRQ: U5.8 (IRQ); also elsewhere on the board
MISO: U5.7 (MISO); also elsewhere on the board
MOSI: U5.6 (MOSI); also elsewhere on the board
unnamed: Q2.1 (B), R12.1
unnamed: D2.A, K2.A1, Q2.3 (C)
unnamed: D1.A, K1.A1, Q1.3 (C)
unnamed: C19.1, U11.6 (FILTER)
unnamed: C17.1, U10.6 (FILTER)
unnamed: Q1.1 (B), R11.1
unnamed: D4.A, R15.1, R16.1
unnamed: D3.A, R13.1, R14.1
unnamed: R10.1, U6.7 (MFP)
RELAY1: R11.2; also elsewhere on the board
RELAY2: R12.2; also elsewhere on the board
RELAY_OUT_1: J8.3, K1.14, K1.14-1 (14)
RELAY_OUT_2: J9.3, K2.14, K2.14-1 (14)
SCK: U5.5 (SCK); also elsewhere on the board
SCL: U6.6 (SCL); also elsewhere on the board
SDA: U6.5 (SDA); also elsewhere on the board
VBAT_3V: BH1.+$1 (+), BH1.+$2 (+1), U6.3 (VBAT)
VCC: C16.1, C18.1, C20.1, D1.C, D2.C, K1.A2, K2.A2, R10.2, U6.8 (VCC), U10.8 (VCC), U11.8 (VCC); also elsewhere on the board
VCC3.3: C12.1, C13.2, R9.1, U5.2 (VCC); also elsewhere on the board
VOUT1: R13.2, U10.7 (VOUT)
VOUT2: R15.2, U11.7 (VOUT)
X1: C15.1, U6.1 (X1), Y2.2
X2: C14.1, U6.2 (X2), Y2.1

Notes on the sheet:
NRF24L01+
Relay Contorller 1
ACS712 Controller 1
Socket Source
Fuse Holder
RTC
Relay Controller 2
Socket Controller 1
Socket Controller 2
ACS712 Controller 2

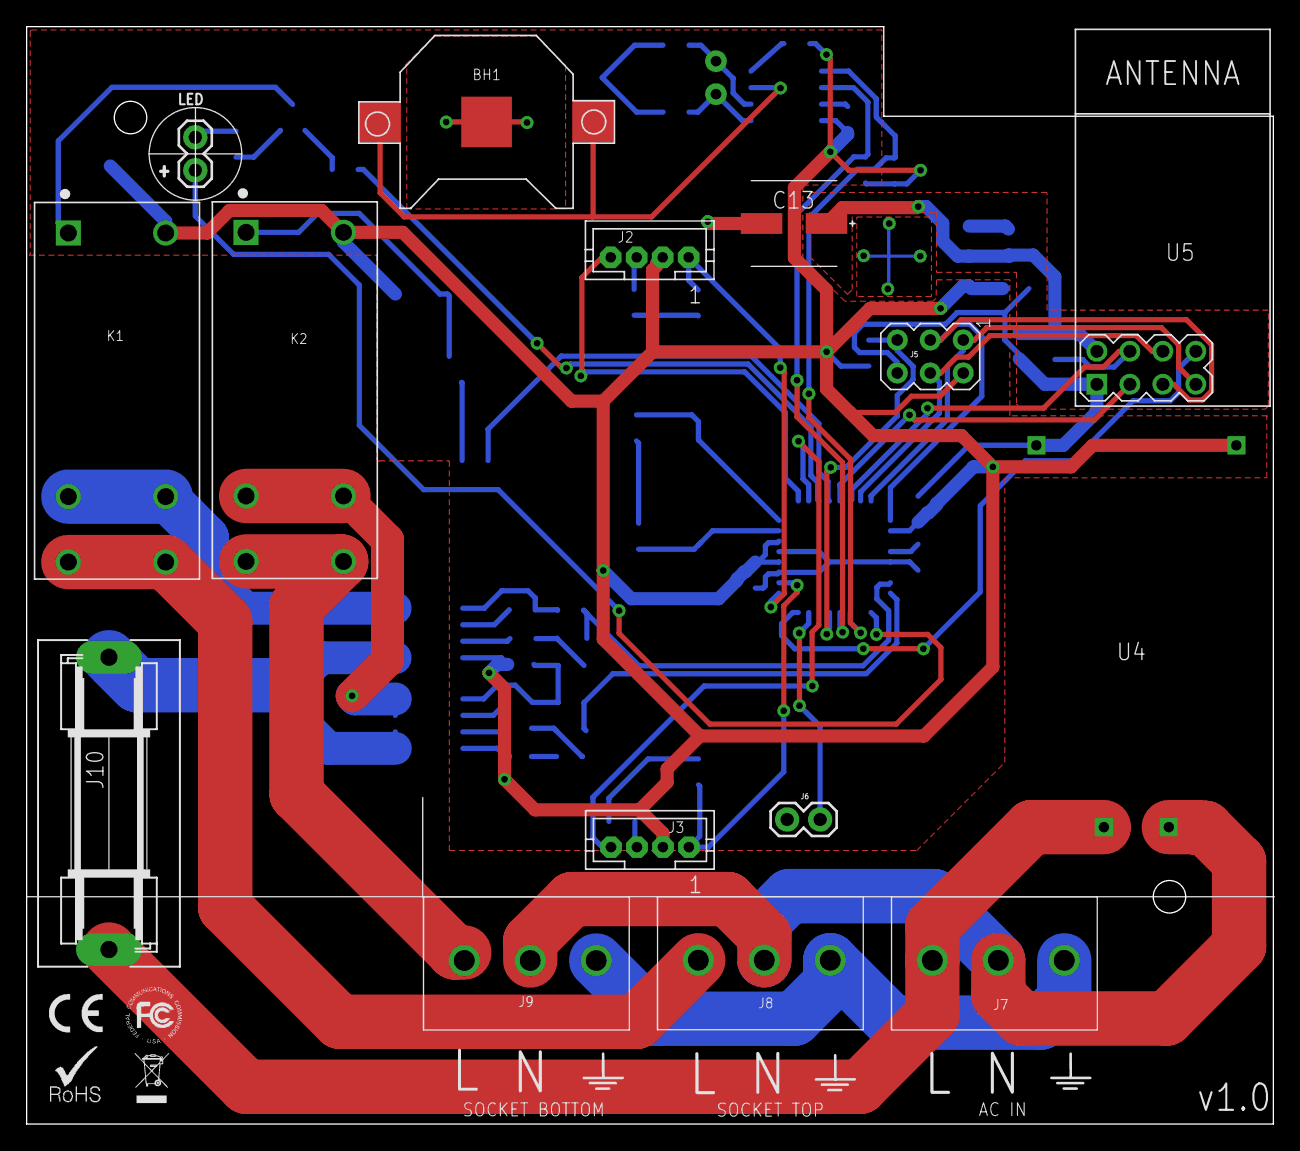
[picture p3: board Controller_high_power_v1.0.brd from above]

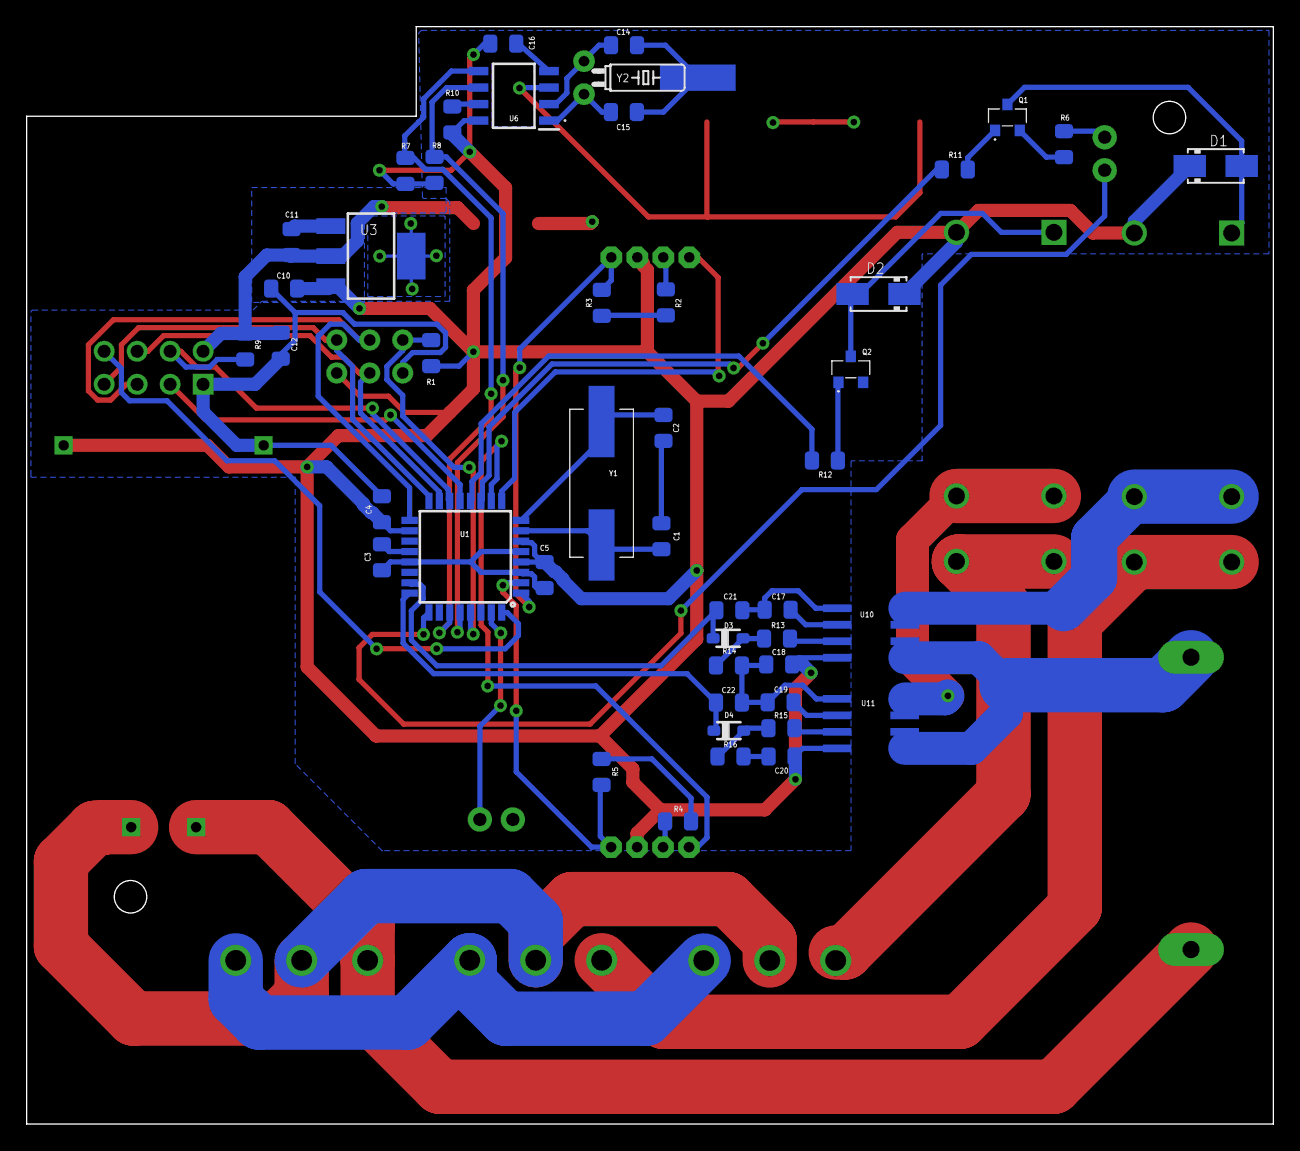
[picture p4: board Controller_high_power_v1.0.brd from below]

Board: 2 copper layers, 96.0 x 84.5 mm, 61 parts (46 on the bottom side), 50 nets.

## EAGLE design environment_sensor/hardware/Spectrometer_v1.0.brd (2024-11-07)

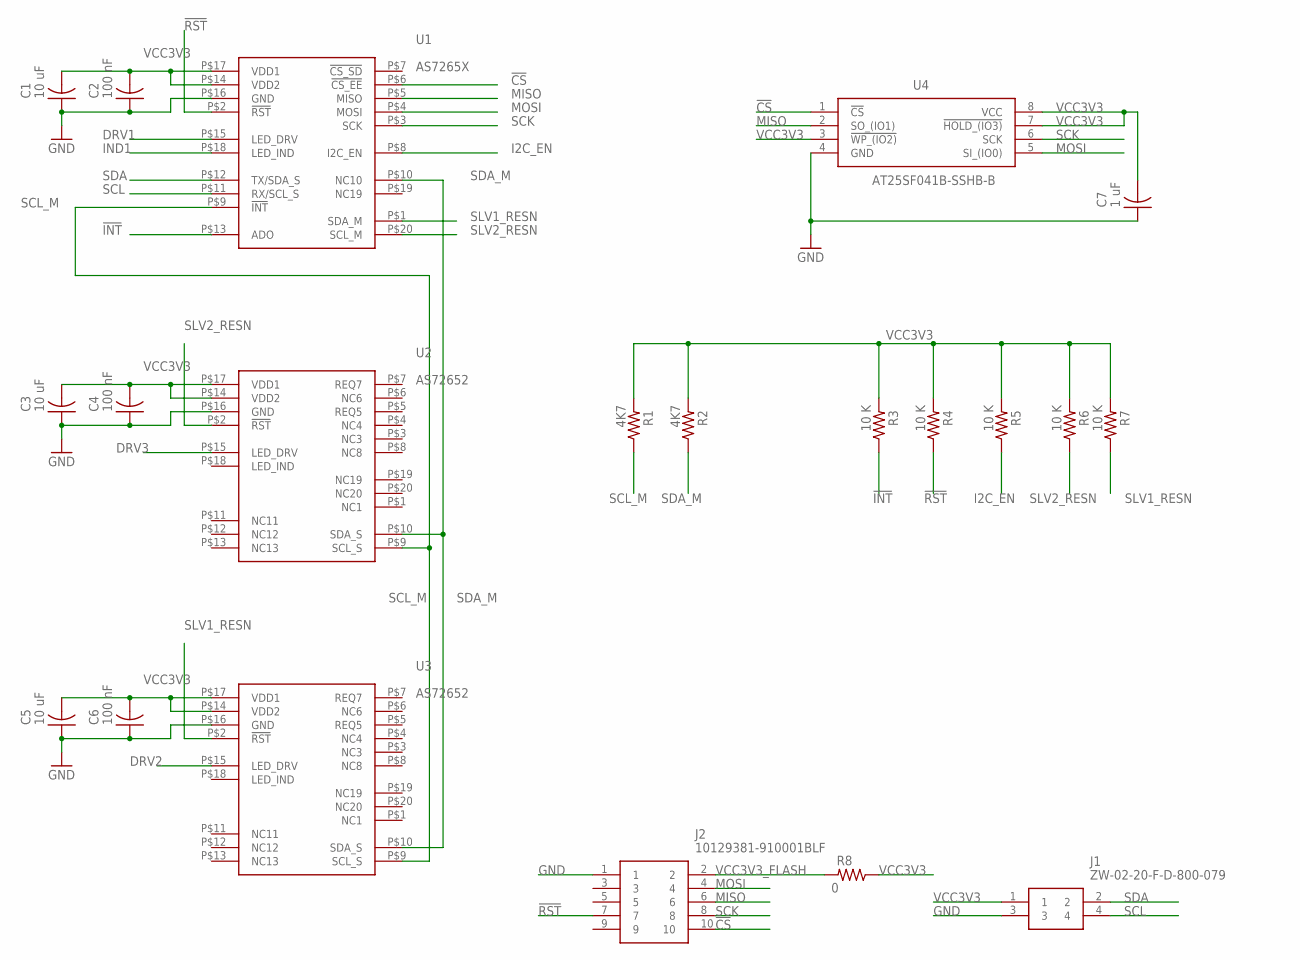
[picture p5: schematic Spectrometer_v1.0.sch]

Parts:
C1, C3, C5: 10 uF; SMD-0805
C2, C4, C6: 100 nF; SMD-0805
C7: 1 uF; SMD-0805
J1: ZW-02-20-F-D-800-079; HDRV4W64P254_2X2_508X508X2669P
J2: 10129381-910001BLF; HDRV10W67P254_2X5_1270X483X858
R1, R2: 4K7; SMD-0805
R3, R4, R5, R6, R7: 10 K; SMD-0805
R8: 0; SMD-0805
U1: AS7265X
U2, U3: AS72652; AS7265X
U4: AT25SF041B-SSHB-B; SOIC127P600X175-8N

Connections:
!CS: J2.10, U1.P$6 (!CS_EE), U4.1 (!CS)
!INT: R3.1, U1.P$13 (ADO)
!RST: J2.7, R4.1, U1.P$2 (!RST)
DRV1: U1.P$15 (LED_DRV)
DRV2: U3.P$15 (LED_DRV)
DRV3: U2.P$15 (LED_DRV)
GND: C1.1, C2.1, C3.1, C4.1, C5.1, C6.1, C7.1, J1.3, J2.1, U1.P$16 (GND), U2.P$16 (GND), U3.P$16 (GND), U4.4 (GND)
I2C_EN: R5.1, U1.P$8 (I2C_EN)
IND1: U1.P$18 (LED_IND)
MISO: J2.6, U1.P$5 (MISO), U4.2 (SO_(IO1))
MOSI: J2.4, U1.P$4 (MOSI), U4.5 (SI_(IO0))
SCK: J2.8, U1.P$3 (SCK), U4.6 (SCK)
SCL: J1.4, U1.P$11 (RX/SCL_S)
SCL_M: R1.1, U1.P$9 (!INT), U2.P$9 (SCL_S), U3.P$9 (SCL_S)
SDA: J1.2, U1.P$12 (TX/SDA_S)
SDA_M: R2.1, U1.P$10 (NC10), U2.P$10 (SDA_S), U3.P$10 (SDA_S)
SLV1_RESN: R7.1, U1.P$1 (SDA_M), U3.P$2 (!RST)
SLV2_RESN: R6.1, U1.P$20 (SCL_M), U2.P$2 (!RST)
VCC3V3: C1.2, C2.2, C3.2, C4.2, C5.2, C6.2, C7.2, J1.1, R1.2, R2.2, R3.2, R4.2, R5.2, R6.2, R7.2, R8.1, U1.P$14 (VDD2), U1.P$17 (VDD1), U2.P$14 (VDD2), U2.P$17 (VDD1), U3.P$14 (VDD2), U3.P$17 (VDD1), U4.3 (!WP_(IO2)), U4.7 (!HOLD_(IO3)), U4.8 (VCC)
VCC3V3_FLASH: J2.2, R8.2

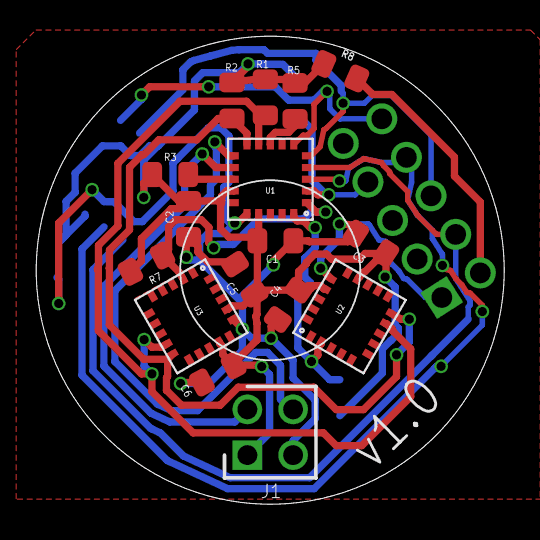
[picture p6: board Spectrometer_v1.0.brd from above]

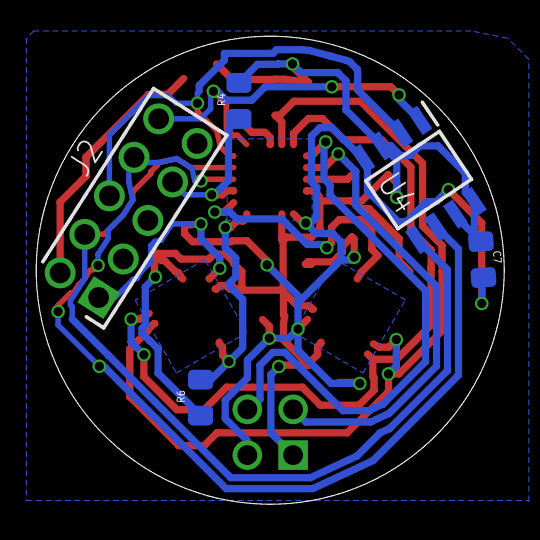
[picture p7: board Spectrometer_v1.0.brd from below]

Board: 2 copper layers, 26.0 x 26.0 mm, 21 parts (5 on the bottom side), 16 nets.

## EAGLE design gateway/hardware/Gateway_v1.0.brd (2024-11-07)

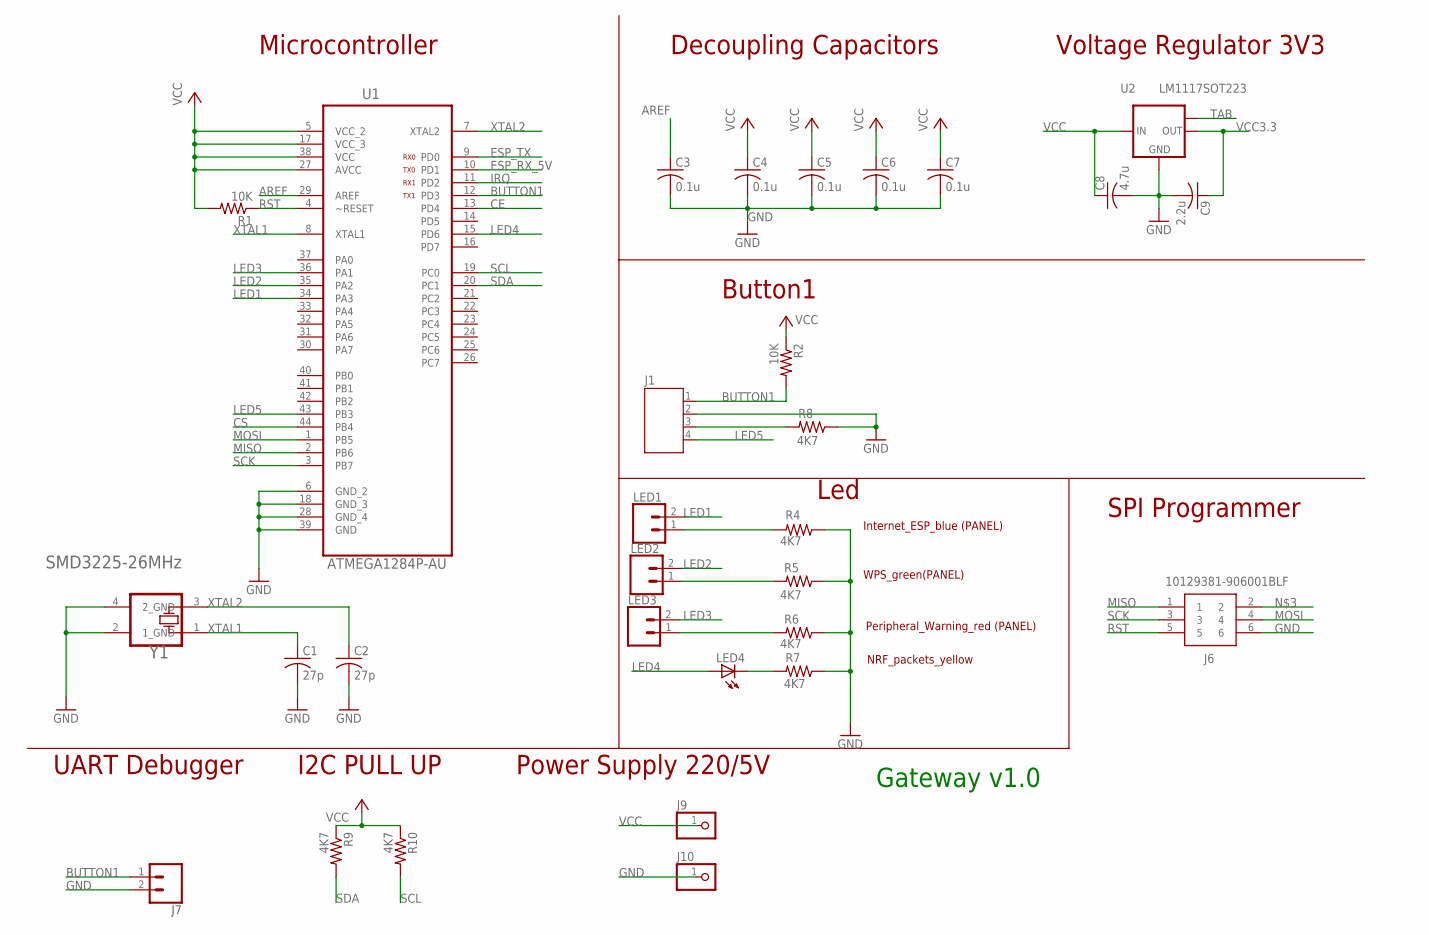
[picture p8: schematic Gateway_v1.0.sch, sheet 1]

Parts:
C1, C2: 27p; SMD-0805
C3, C4, C5, C6, C7: 0.1u; SMD-0805
C8: 4.7u; SMD-0805
C9: 2.2u; SMD-0805
J1: JST-PH4
J6: 10129381-906001BLF; HDRV6W67P254_2X3_762X483X858P
J7: CONN_02; 1X02
J9, J10: PINHD-1X1CB; 1X01-CLEANBIG
LED1, LED2, LED3: CONN_02; 1X02
LED4: LED4; SMD-0805-LED
R1, R2: 10K; SMD-0805
R4, R5, R6, R7, R8, R9, R10: 4K7; SMD-0805
U1: ATMEGA1284P-AU; QFP80P1200X1200X120-44N
U2: LM1117SOT223; SOT223
Y1: TND_ELECTRONIC_SMD3225-26MHZTND_ELECTRONIC_SMD322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; TND_ELECTRONIC_SMD3225-26MHZ_0

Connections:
AREF: C3.1, U1.29 (AREF)
BUTTON1: J1.1, J7.1, R2.2, U1.12 (PD3)
CE: U1.13 (PD4); also elsewhere on the board
CS: U1.44 (PB4); also elsewhere on the board
ESP_RX_5V: U1.10 (PD1); also elsewhere on the board
ESP_TX: U1.9 (PD0); also elsewhere on the board
GND: C1.2, C2.2, C3.2, C4.2, C5.2, C6.2, C7.2, C8.2, C9.2, J1.2, J6.6, J7.2, J10.1, R4.1, R5.1, R6.1, R7.1, R8.1, U1.6 (GND_2), U1.18 (GND_3), U1.28 (GND_4), U1.39 (GND), U2.1 (GND), Y1.2 (1_GND), Y1.4 (2_GND); also elsewhere on the board
IRQ: U1.11 (PD2); also elsewhere on the board
LED1: LED1.2, U1.34 (PA3)
LED2: LED2.2, U1.35 (PA2)
LED3: LED3.2, U1.36 (PA1)
LED4: LED4.1 (A), U1.15 (PD6)
LED5: J1.4, U1.43 (PB3)
MISO: J6.1, U1.2 (PB6); also elsewhere on the board
MOSI: J6.4, U1.1 (PB5); also elsewhere on the board
unnamed: LED2.1, R5.2
unnamed: LED3.1, R6.2
unnamed: LED1.1, R4.2
unnamed: J1.3, R8.2
unnamed: LED4.2 (C), R7.2
RST: J6.5, R1.1, U1.4 (~RESET)
SCK: J6.3, U1.3 (PB7); also elsewhere on the board
SCL: R10.2, U1.19 (PC0); also elsewhere on the board
SDA: R9.2, U1.20 (PC1); also elsewhere on the board
VCC: C4.1, C5.1, C6.1, C7.1, C8.1, J9.1, R1.2, R2.1, R9.1, R10.1, U1.5 (VCC_2), U1.17 (VCC_3), U1.27 (AVCC), U1.38 (VCC), U2.3 (IN); also elsewhere on the board
VCC3.3: C9.1, U2.2 (OUT); also elsewhere on the board
XTAL1: C1.1, U1.8 (XTAL1), Y1.1 (X1)
XTAL2: C2.1, U1.7 (XTAL2), Y1.3 (X2)
ΤΑΒ: U2.TAB (OUT1)

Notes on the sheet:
Gateway v1.0
Decoupling Capacitors
Voltage Regulator 3V3
Microcontroller
UART Debugger
SPI Programmer
I2C PULL UP
Led
Button1
TX1
RX1
Power Supply 220/5V
Internet_ESP_blue (PANEL)
NRF_packets_yellow
Peripheral_Warning_red (PANEL)
WPS_green(PANEL)
TX0
RX0

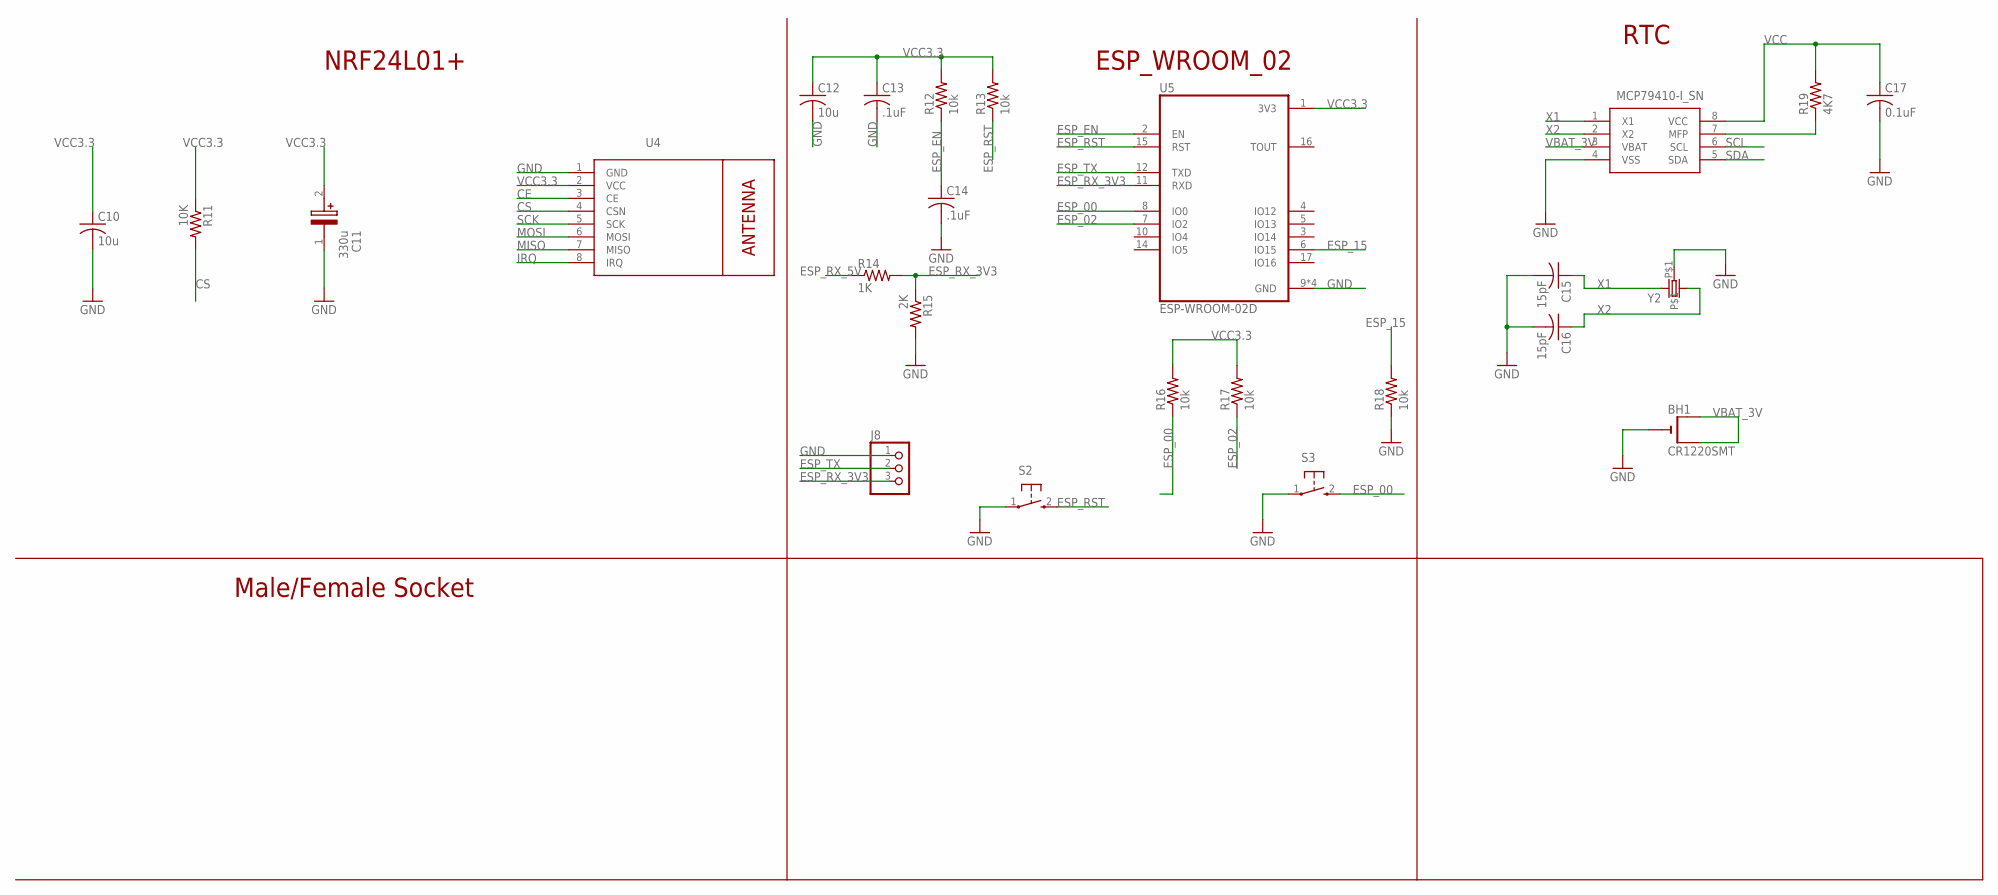
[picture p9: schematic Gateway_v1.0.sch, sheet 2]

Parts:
BH1: CR1220SMT; CR1220-SMD
C10, C12: 10u; SMD-0805
C11: 330u; SMD_LYTIC_D8
C13, C14: .1uF; SMD-0805
C15, C16: 15pF; SMD-0805
C17: 0.1uF; SMD-0805
J8: PINHD-1X3; 1X03
R11: 10K; SMD-0805
R12, R13, R16, R17, R18: 10k; SMD-0805
R14: 1K; SMD-0805
R15: 2K; SMD-0805
R19: 4K7; SMD-0805
S2, S3: SPST_TACT-KMR2; KMR2
U4: WIRELESS-NRF24L01
U5: ESP-WROOM-02D; MODULE_ESP-WROOM-02D
U6: MCP79410-I_SN; SOIC127P600X175-8N
Y2: CRYSTALTC26H; TC26H

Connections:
CE: U4.3 (CE); also elsewhere on the board
CS: R11.2, U4.4 (CSN); also elsewhere on the board
ESP_00: R16.1, S3.2 (S), U5.8 (IO0)
ESP_02: R17.1, U5.7 (IO2)
ESP_15: R18.2, U5.6 (IO15)
ESP_EN: C14.1, R12.1, U5.2 (EN)
ESP_RST: R13.1, S2.2 (S), U5.15 (RST)
ESP_RX_3V3: J8.3, R14.2, R15.1, U5.11 (RXD)
ESP_RX_5V: R14.1; also elsewhere on the board
ESP_TX: J8.2, U5.12 (TXD); also elsewhere on the board
GND: BH1.-, C10.2, C11.1, C12.2, C13.2, C14.2, C15.2, C16.2, C17.2, J8.1, R15.2, R18.1, S2.1, S3.1, U4.1 (GND), U5.9 (GND), U5.13 (GND), U5.18 (GND), U5.19 (GND), U6.4 (VSS), Y2.P$1; also elsewhere on the board
IRQ: U4.8 (IRQ); also elsewhere on the board
MISO: U4.7 (MISO); also elsewhere on the board
MOSI: U4.6 (MOSI); also elsewhere on the board
unnamed: R19.1, U6.7 (MFP)
SCK: U4.5 (SCK); also elsewhere on the board
SCL: U6.6 (SCL); also elsewhere on the board
SDA: U6.5 (SDA); also elsewhere on the board
VBAT_3V: BH1.+$1 (+), BH1.+$2 (+1), U6.3 (VBAT)
VCC: C17.1, R19.2, U6.8 (VCC); also elsewhere on the board
VCC3.3: C10.1, C11.2, C12.1, C13.1, R11.1, R12.2, R13.2, R16.2, R17.2, U4.2 (VCC), U5.1 (3V3); also elsewhere on the board
X1: C15.1, U6.1 (X1), Y2.2
X2: C16.1, U6.2 (X2), Y2.1

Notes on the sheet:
NRF24L01+
ESP_WROOM_02
Male/Female Socket
RTC

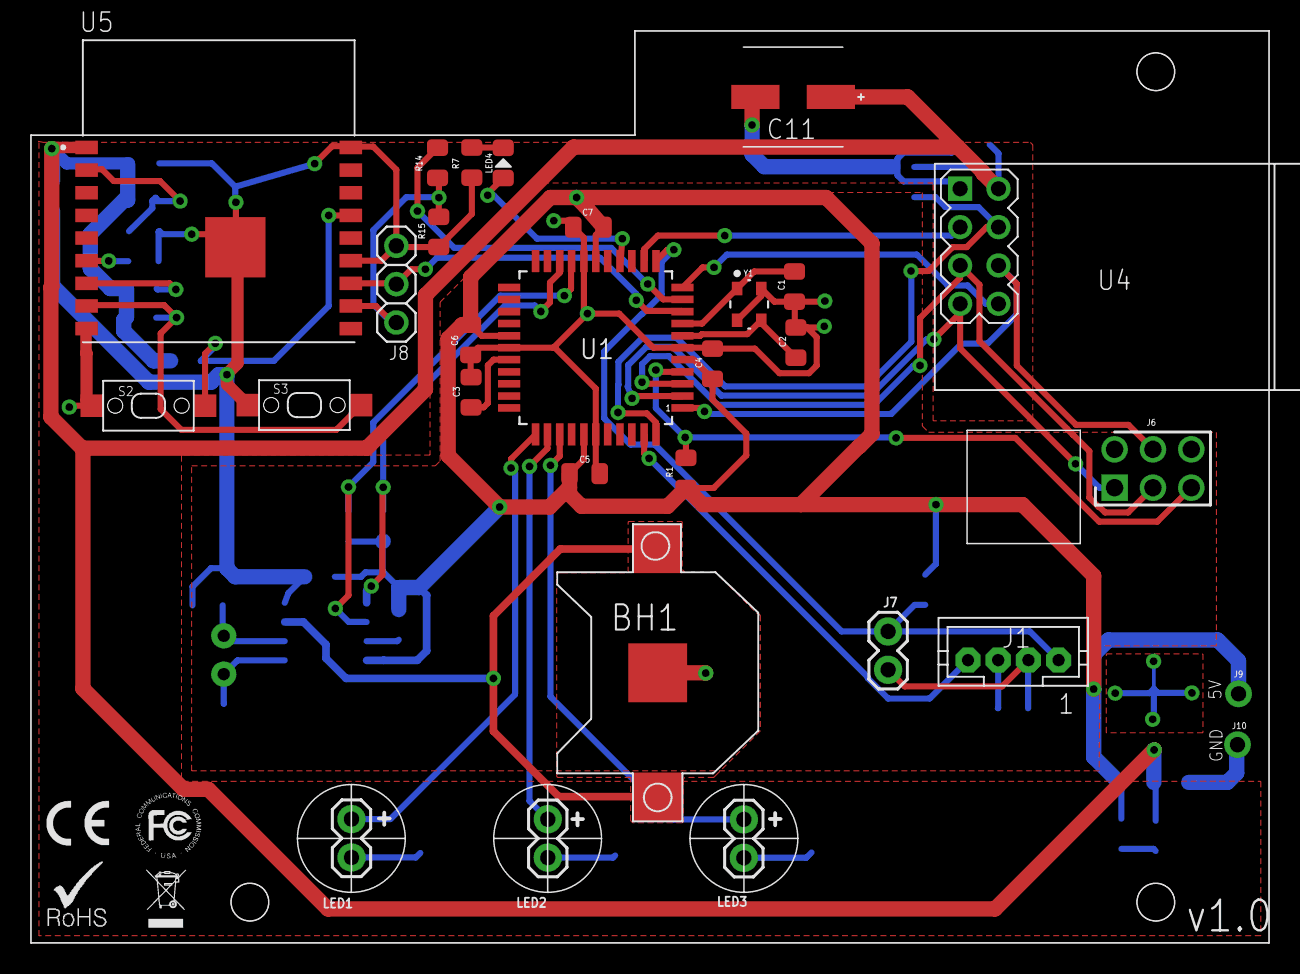
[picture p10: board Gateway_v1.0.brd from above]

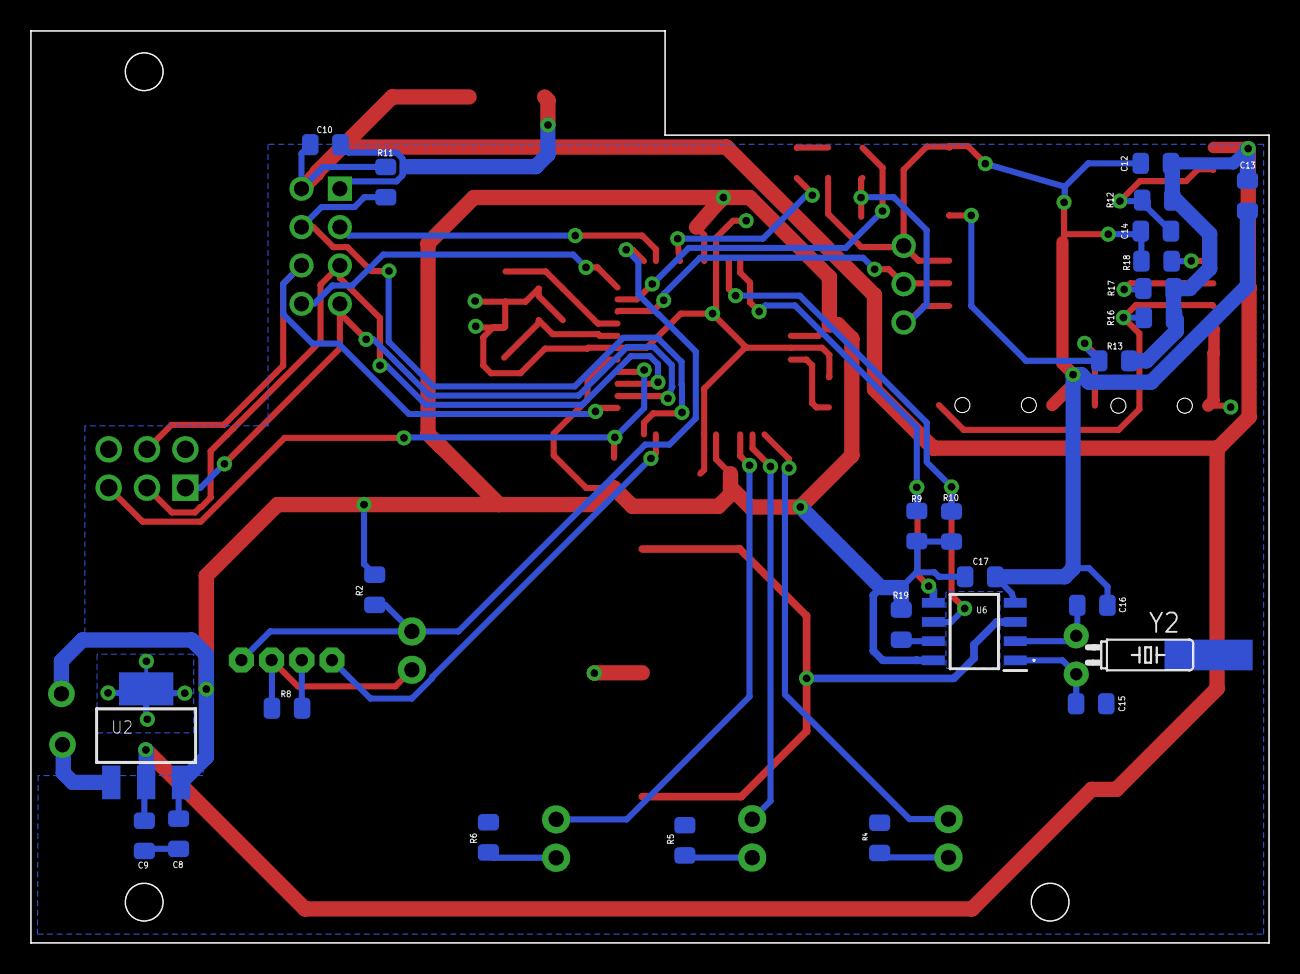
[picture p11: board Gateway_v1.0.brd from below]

Board: 2 copper layers, 82.0 x 60.4 mm, 55 parts (26 on the bottom side), 38 nets.

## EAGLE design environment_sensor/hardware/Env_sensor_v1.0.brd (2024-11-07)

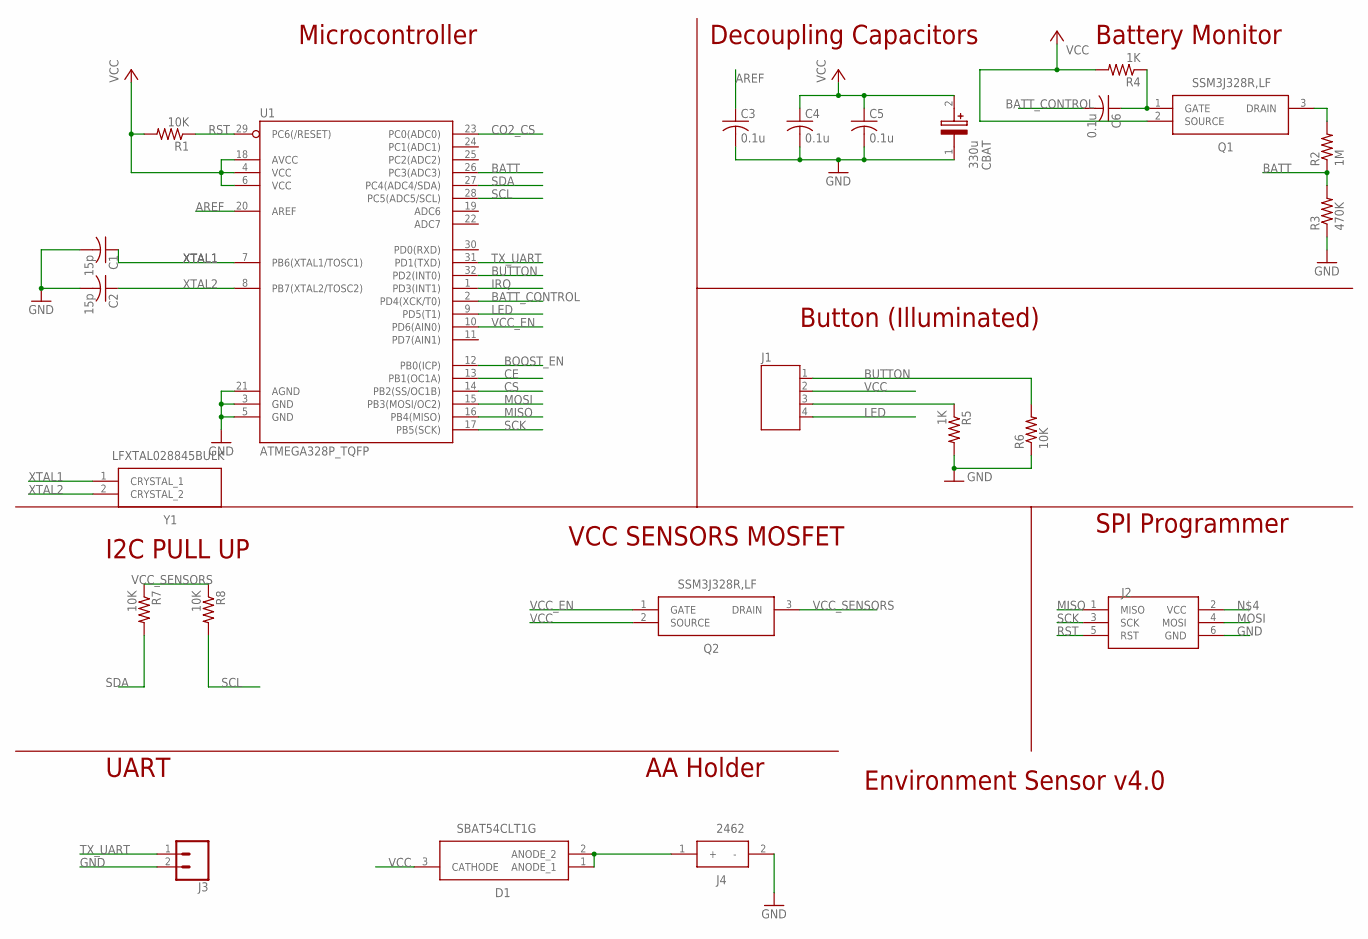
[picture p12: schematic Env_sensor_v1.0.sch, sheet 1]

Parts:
C1, C2: 15p; SMD-0805
C3, C4, C5, C6: 0.1u; SMD-0805
CBAT: 330u; SMD_LYTIC_D8
D1: SBAT54CLT1G; SOT96P237X111-3N
J1: JST-PH4
J2: ISP; AVRISP
J3: CONN_02; 1X02
J4: 2462
Q1, Q2: SSM3J328R,LF; SOTFL95P240X88-3N
R1, R6, R7, R8: 10K; SMD-0805
R2: 1M; SMD-0805
R3: 470K; SMD-0805
R4, R5: 1K; SMD-0805
U1: ATMEGA328P_TQFP; TQFP32-08
Y1: LFXTAL028845BULK

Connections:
AREF: C3.1, U1.20 (AREF)
BATT: R2.1, R3.2, U1.26 (PC3(ADC3))
BATT_CONTROL: C6.2, U1.2 (PD4(XCK/T0))
BOOST_EN: U1.12 (PB0(ICP)); also elsewhere on the board
BUTTON: J1.1, R6.2, U1.32 (PD2(INT0))
CE: U1.13 (PB1(OC1A)); also elsewhere on the board
CO2_CS: U1.23 (PC0(ADC0)); also elsewhere on the board
CS: U1.14 (PB2(SS/OC1B)); also elsewhere on the board
GND: C1.2, C2.2, C3.2, C4.2, C5.2, CBAT.1, J2.6 (GND), J3.2, J4.2 (-), R3.1, R5.2, R6.1, U1.3 (GND), U1.5 (GND), U1.21 (AGND); also elsewhere on the board
IRQ: U1.1 (PD3(INT1)); also elsewhere on the board
LED: J1.4, U1.9 (PD5(T1))
MISO: J2.1 (MISO), U1.16 (PB4(MISO)); also elsewhere on the board
MOSI: J2.4 (MOSI), U1.15 (PB3(MOSI/OC2)); also elsewhere on the board
unnamed: Q1.3 (DRAIN), R2.2
unnamed: D1.1 (ANODE_1), D1.2 (ANODE_2), J4.1 (+)
unnamed: J1.3, R5.1
unnamed: C6.1, Q1.1 (GATE), R4.1
RST: J2.5 (RST), R1.1, U1.29 (PC6(/RESET))
SCK: J2.3 (SCK), U1.17 (PB5(SCK)); also elsewhere on the board
SCL: R8.2, U1.28 (PC5(ADC5/SCL)); also elsewhere on the board
SDA: R7.2, U1.27 (PC4(ADC4/SDA)); also elsewhere on the board
TX_UART: J3.1, U1.31 (PD1(TXD))
VCC: C4.1, C5.1, CBAT.2, D1.3 (CATHODE), J1.2, Q1.2 (SOURCE), Q2.2 (SOURCE), R1.2, R4.2, U1.4 (VCC), U1.6 (VCC), U1.18 (AVCC); also elsewhere on the board
VCC_EN: Q2.1 (GATE), U1.10 (PD6(AIN0))
VCC_SENSORS: Q2.3 (DRAIN), R7.1, R8.1; also elsewhere on the board
XTAL1: C1.1, U1.7 (PB6(XTAL1/TOSC1)), Y1.1 (CRYSTAL_1)
XTAL2: C2.1, U1.8 (PB7(XTAL2/TOSC2)), Y1.2 (CRYSTAL_2)

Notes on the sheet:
Environment Sensor v4.0
Decoupling Capacitors
Battery Monitor
SPI Programmer
Microcontroller
UART
AA Holder
Button (Illuminated)
I2C PULL UP
VCC SENSORS MOSFET


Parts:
C7: 10u; SMD-0805
C8, C14, C15, C17: 0.1u; SMD-0805
C9: 0.220u; SMD-0805
C10: 2.2u; SMD-0805
C11, C12: 1uF; SMD-0805
C13: 2.2uF; SMD-0805
C16: 4.7u; SMD-0805
J5: ZW-02-20-F-D-800-079; HDRV4W64P254_2X2_508X508X2669P
R9: 10K; SMD-0805
U2: NRF24L01+; WIRELESS-NRF24L01
U3: SHT40-AD1B-R2; XDCR_SHT40-AD1B-R2
U4: USEQGSEAC82180
U5: TCA9406DCTR; SOP65P400X130-8N
U6: TPS60205; SOP50P488X107-10N

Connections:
BOOST_EN: U6.9 (EN); also elsewhere on the board
CE: U2.3 (CE); also elsewhere on the board
CO2_CS: U4.23 (CS); also elsewhere on the board
CS: R9.2, U2.4 (CSN); also elsewhere on the board
GND: C7.2, C8.2, C9.2, C10.2, C13.2, C14.2, C15.2, C16.2, C17.2, J5.3, U2.1 (GND), U3.4 (VSS), U4.5 (GND_1), U4.7 (GND_2), U4.17 (GND_3), U4.19 (GND_4), U4.28 (GND_5), U4.29 (GND_6), U4.30 (GND_7), U5.2 (GND), U6.1 (GND_1), U6.2 (GND_2); also elsewhere on the board
IRQ: U2.8 (IRQ); also elsewhere on the board
MISO: U2.7 (MISO); also elsewhere on the board
MOSI: U2.6 (MOSI); also elsewhere on the board
unnamed: C9.1, U4.3 (CAP)
unnamed: C11.1, U6.4 (C1+)
unnamed: C11.2, U6.3 (C1-)
unnamed: C12.1, U6.6 (C2+)
unnamed: C12.2, U6.8 (C2-)
SCK: U2.5 (SCK); also elsewhere on the board
SCL: U3.2 (SCL), U4.27 (SCL), U5.8 (SCL_B); also elsewhere on the board
SCL_BRD: J5.4, U5.5 (SCL_A)
SDA: U3.1 (SDA), U4.26 (SDA), U5.1 (SDA_B); also elsewhere on the board
SDA_BRD: J5.2, U5.4 (SDA_A)
VCC: C7.1, R9.1, U2.2 (VCC); also elsewhere on the board
VCC3V3: C13.1, C15.1, J5.1, U5.7 (VCCB), U6.5 (OUT)
VCC_SENSORS: C8.1, C10.1, C14.1, C16.1, C17.1, U3.3 (VDD), U4.1 (VSUPPLY), U5.3 (VCCA), U5.6 (OE), U6.7 (IN); also elsewhere on the board

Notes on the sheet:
NRF24L01+
Si7021
Spectometer
CO2
Step Up Converter 3.3V



Board: 2 copper layers, 82.3 x 60.4 mm, 42 parts (31 on the bottom side), 35 nets.

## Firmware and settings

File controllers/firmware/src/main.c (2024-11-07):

/*
* @file main.c
*
* @brief Main file
*
*/

#include "PinsAndMacros.h"

// Standard libraries
#include <string.h>
#include <stdlib.h>
#include <stdio.h>
#include <stdint.h>
#include <stdbool.h>
#include <util/delay.h>

// AVR-specific libraries
#include <avr/io.h>
#include <avr/interrupt.h>
#include <avr/wdt.h>

#include "CONSOLE_log.h"
#include "CONTROLLER_HP.h"

// Static variables
volatile static uint8_t WD_INT = 0;

// Main function
int main(void)
{
	WDT_INIT;
	HW_INIT;
	TIMERS_INIT;
		
	CONTROLLER_HP_init();
						
	while(1) 
    {
		CONTROLLER_HP_cycle_start(); 
		CONTROLLER_HP_measurements();
		CONTROLLER_HP_tasks();
		CONTROLLER_HP_connection();
		CONTROLLER_HP_cycle_end();
		wdt_reset();	
		// Cycle++
    }
}

// Watchdog Interrupt - NOT USED
ISR(WDT_vect)
{

}

// NRF24L01 IRQ pin
ISR(INT0_vect) 
{
	NRF_IRQ = 1;
}

// Interrupt 1 - NOT USED
ISR(INT1_vect) 
{

}

// Timer 0 - CTC mode 50ms - Main LED
ISR(TIMER0_COMPA_vect)	
{
	// Led state current
	static Led_state_t led_state = LED_STATE_BLINK_1S;	
	// Led state next
	Led_state_t led_state_next = g_led_state;
	
	if (g_led_flash != LED_FLASH_NONE && led_state != LED_STATE_FLASH)
	{	
		led_state = LED_STATE_FLASH;
		g_led_ticks = 0;
	}
	
	switch (led_state)
	{
		case LED_STATE_ON:
			if (led_state != led_state_next)
			{
				LED_OFF;
				led_state = led_state_next;
				g_led_ticks = 0;
				break;
			}	
			LED_ON;	
			break;
			
		case LED_STATE_OFF:
			LED_OFF;	
			led_state = led_state_next;
			break;
			
		case LED_STATE_BLINK_1S: // First OFF Then On
			g_led_ticks++;
			if (g_led_ticks >= 19)
			{
				g_led_ticks = 0;
				
				if (led_state != led_state_next)
				{
					led_state = led_state_next;
					break;
				}
				LED_TOGGLE;	
			}
			break;
			
		case LED_STATE_BLINK_500MS:
			g_led_ticks++;
			
			if (g_led_ticks >= 9)
			{
				g_led_ticks = 0;
				
				// Next state
				if (led_state != led_state_next)
				{
					led_state = led_state_next;
					break;
				}				
				LED_TOGGLE;
			}			
			break;
		
		case LED_STATE_FLASH:
			g_led_ticks++;
			LED_TOGGLE;
			
			if (g_led_ticks >= (uint16_t)g_led_flash)
			{
				g_led_ticks = 0;
				led_state = led_state_next;
				g_led_flash = LED_FLASH_NONE;
			}
			break;
		
		default:
			break;
	}
}

// Timer 2 - CTC mode 10ms - Buttons
ISR(TIMER2_COMPA_vect)
{
	uint8_t current_state = BUTTON_2_STATE;	
		
	switch (g_button_2)
	{
		case BUTTON_UNPRESSED:
			if (current_state)
			{
				g_button_2_ticks = 0;
				g_button_2 = BUTTON_IN_PROGRESS;
			}
			break;
			
		case BUTTON_IN_PROGRESS:
			g_button_2_ticks++;
				
			if (g_button_2_ticks >= BUTTON_LONG_PRESS_TICKS)
			{
				// LED blink to indicate that long press is achieved
				g_led_flash = LED_FLASH_1_SEC;
			}
				
			if (!current_state)
			{
				if (g_button_2_ticks >= BUTTON_LONG_PRESS_TICKS)
				{
						
					g_button_2 = BUTTON_LONG_PRESS;
				}
				else
				{
					g_button_2 = BUTTON_SHORT_PRESS;
				}
			}

			break;
			
		case BUTTON_SHORT_PRESS:
		case BUTTON_LONG_PRESS:
			g_button_2_ticks = 0;
			break;
			
		default:
			break;
	}		
}

/*** end of file ***/

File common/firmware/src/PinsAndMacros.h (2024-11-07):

/*
* @file PinsAndMacros.h
*
* @brief Pin and macros.
*
*/

#ifndef PINS_AND_MACROS_H
#define PINS_AND_MACROS_H

#define GETBIT(x) (1 << (x)) /* Get bit y in byte x*/
#define SETBIT(x,y) (x |= (y)) /* Set bit y in byte x*/
#define CLEARBIT(x,y) (x &= (~y)) /* Clear bit y in byte x*/
#define CHECKBIT(x,y) (x & (y)) /* Check bit y in byte x*/
#define _STRINGIZE(x) #x
#define STRINGIZE(x) _STRINGIZE(x)
	
/************************************************************************************
******************************** Gateway ********************************************
************************************************************************************/

#ifdef GATEWAY

// CPU Frequency
#define F_CPU 16000000UL

// SPI Pins for SPI library
#define SPI_PORT PORTB
#define SPI_DDR  DDRB
#define SPI_SCK  DDB7
#define SPI_MISO DDB6
#define SPI_MOSI DDB5
#define SPI_SS   DDB4

// CS and CE for NRF24L01
#define RF_CE		DDD4 // PD4
#define RF_CSN		DDB4 // PB4
#define RF_CE_INIT	DDRD |=  (1 << RF_CE);
#define RF_CS_INIT  DDRB |=  (1 << RF_CSN);
#define RF_CE_HIGH  PORTD |=  (1 << RF_CE);
#define RF_CE_LOW   PORTD &= ~(1 << RF_CE);
#define RF_CE_STATE (PORTB&GETBIT(RF_CE))
#define RF_CS_HIGH  PORTB |=  (1 << RF_CSN);
#define RF_CS_LOW   PORTB &= ~(1 << RF_CSN);

// Timers
#define TIMER_0 TCNT0
#define TIMER_1 TCNT1
#define TIMER_2 TCNT2
#define TIMER_0_TICK_MS		0.064
#define TIMER_1_TICK_MS		0.064
#define TIMER_2_TICK_MS		0.064

// Modules/Leds/Buttons
#define CONSUMPTION	0x04	// PA2
#define RELAY1		0x08	// PA3
#define NRF_CONTROL	0x20	// PD5
#define ESP_CONTROL	0x10	// PA4
#define BUTTON_1	0x04	// PB2
#define BUTTON_3	0x02	// PA1
#define LED1 0x02			// PB1
#define LED2 0x01			// PB0
#define LED3 0x01			// PA0
#define LED4 0x40 			// PD6
#define LED5 0x08			// PB3

#define consumption_init	DDRA&=~CONSUMPTION
#define relay_1_init	DDRA|=RELAY1
#define relay_1_on		PORTA|=RELAY1
#define relay_1_off		PORTA&=~RELAY1
#define relay_1_toggle	PORTA^=RELAY1
#define relay_1_read	((PORTA&RELAY1)>>3)

#define button_1_init	DDRB&=~BUTTON_1
#define button_1_pushed !(PINB&BUTTON_1)
#define button_1_pushed_seconds 3

#define led_1_init		DDRB|=LED1		// Internet
#define led_1_on		PORTB|=LED1
#define led_1_off		PORTB&=~LED1
#define led_1_toggle	PORTB^=LED1

#define led_2_init		DDRB|=LED2		// WPS
#define led_2_on		PORTB|=LED2
#define led_2_off		PORTB&=~LED2
#define led_2_toggle	PORTB^=LED2

#define led_3_init		DDRA|=LED3		// Warning
#define led_3_on		PORTA|=LED3
#define led_3_off		PORTA&=~LED3
#define led_3_toggle	PORTA^=LED3

#define led_4_init		DDRD|=LED4		// NRF packets
#define led_4_on		PORTD|=LED4
#define led_4_off		PORTD&=~LED4
#define led_4_toggle	PORTD^=LED4

#define led_5_init		DDRB|=LED5		// Relay status
#define led_5_on		PORTB|=LED5
#define led_5_off		PORTB&=~LED5
#define led_5_toggle	PORTB^=LED5


#define INTERNET_LED_ON			{TIMSK0&=(0 << OCIE0A); led_1_on;}
#define INTERNET_LED_OFF		{TIMSK0&=(0 << OCIE0A); led_1_off;}
#define INTERNET_LED_BLINK_MODE	{TIMSK0|=(1 << OCIE0A); TCNT0 = 0; INTERNET_LED_FAST }
#define INTERNET_LED_SLOW		OCR0A=157;
#define INTERNET_LED_NORMAL		OCR0A=100;
#define INTERNET_LED_FAST		OCR0A=38;
#define INTERNET_LED_SUPER_FAST	OCR0A=13;

// Tested - OK
//#define INTERNET_LED_ON			{TIMSK0&=(0 << OCIE0A); led_1_on;}
//#define INTERNET_LED_OFF		{TIMSK0&=(0 << OCIE0A); led_1_off;}
//#define INTERNET_LED_BLINK_MODE	{TIMSK0|=(1 << OCIE0A);}
//#define INTERNET_LED_SLOW		{OCR0A=157; TCNT0 = 0;}
//#define INTERNET_LED_NORMAL		{OCR0A=100; TCNT0 = 0;} // untested
//#define INTERNET_LED_FAST		{OCR0A=38; TCNT0 = 0;}
//#define INTERNET_LED_SUPER_FAST	{OCR0A=13; TCNT0 = 0;}


#define interrupt_0_init	{ EICRA |= _BV(ISC01); EIMSK |= _BV(INT0); }	// IRQ
#define interrupt_1_init	{ EICRA |= _BV(ISC11); EIMSK |= _BV(INT1); }	// Button2 - TX_debug
#define interrupt_2_init	{ EICRA |= _BV(ISC21); EIMSK |= _BV(INT2); }	// Button1

//interrupt_1_init; // Disabled because we need TX debug TODO

#define HW_INIT_GW { consumption_init; relay_1_init; button_1_init; led_1_init; led_2_init; led_3_init; led_4_init; led_5_init; interrupt_0_init; interrupt_2_init; sei(); }
	
#define WDT_INIT_GW { cli(); MCUSR &= ~(1<<WDRF); WDTCSR = (1<<WDCE)|(1<<WDE); WDTCSR = (1<<WDIE)|(0<<WDE)|(1<<WDP3)|(0<<WDP2)|(0<<WDP1|(0<<WDP0)); sei(); wdt_enable(WDTO_4S); }

/*
	Interrupts
	0 0 The low level of INTn generates an interrupt request
	0 1 Any edge of INTn generates asynchronously an interrupt request
	1 0 The falling edge of INTn generates asynchronously an interrupt request
	1 1 The rising edge of INTn generates asynchronously an interrupt request


	Watchdog 
	3|2|1|0
 	0|1|0|0		250ms
 	0|1|0|1		500ms
 	0|1|1|0		1s
 	1|0|0|0		4s
*/

#endif

/************************************************************************************
******************************** Soil Sensor ****************************************
************************************************************************************/

#ifdef SOIL_SENSOR
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

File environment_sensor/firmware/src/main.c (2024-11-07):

/*
* @file main.c
*
* @brief Main file
*
*/

#include "PinsAndMacros.h"

// Standard libraries
#include <string.h>
#include <stdlib.h>
#include <stdio.h>
#include <stdint.h>
#include <stdbool.h>
#include <util/delay.h>

// AVR-specific libraries
#include <avr/io.h>
#include <avr/sleep.h>
#include <avr/interrupt.h>
#include <avr/wdt.h>

#include "CONSOLE_log.h"
#include "ENV_SENSOR.h"

// Static variables
time_t g_time_epoch_y2k = 0;
volatile uint8_t g_wake_up = 0;

// Static functions
static void sleep(uint8_t sleep_cycles);

// Main function
int main(void)
{
	HW_INIT;  
	WDT_INIT;
	TIMERS_INIT;
	
	// Sensors ON
	VCC_EN_OFF;		// Reverse logic
	BOOST_EN_ON;
	_delay_ms(1);
	
	ENV_SENSOR_init();
	
	_delay_ms(1000);
		
	while(1) 
    {	
		ENV_SENSOR_power_up();
		ENV_SENSOR_measurements();
		ENV_SENSOR_tasks();
		ENV_SENSOR_connection();	
		ENV_SENSOR_power_down();
		
		// Connect cycles: e.g. 2 [sec] (WDT) * 5 = 10 [sec]
		sleep(SOIL_SENSOR_CONNECT_CYCLES);
    }
}

/*!
* @brief MCU sleep mode for the given number of cycles
*/
static void sleep(uint8_t sleep_cycles)
{
	g_wake_up = 0;
	
	// Set watchdog to Interrupt mode and 2 seconds
	WDT_INIT_SLEEP;
	// Set sleep power down mode
	set_sleep_mode(SLEEP_MODE_PWR_DOWN);
	cli();
	sleep_enable();
	
	for(uint8_t i = 0; i < sleep_cycles; i++)
	{
		// Enable PRR
		PRR = (PRTWI << 1) | (PRTIM2 << 1) | (PRTIM0 << 1) | (PRTIM1 << 1) | (PRSPI << 1) | (PRUSART0 << 1) | (PRADC << 1);
		// Disable BOD before sleep
		sleep_bod_disable();
		// Go to sleep
		sei();
		sleep_cpu();
		// Exit loop if button pushed
		if (g_wake_up)
		{	
			break;
		}
	}
		
	// Wake up!
	sleep_disable();
	// Disable PRR
	PRR = 0x00;
	// Set watchdog to Interrupt & System Reset mode and 2 seconds
	WDT_INIT;
}

ISR(INT0_vect)
{
	// NRF24L01 IRQ pin
	NRF_IRQ = 1;
}

ISR(INT1_vect)
{
	//LED_TOGGLE;
	
	// Used to wake up!
	// NOTE: Button and soil clock 1 share the same pin.
	g_wake_up = 1;
}

ISR(WDT_vect)
{
	// Wake up!
}

ISR(TIMER0_COMPA_vect)
{
	// Unused
}

ISR(TIMER1_COMPA_vect)
{
	// Unused
}

ISR(TIMER2_COMPA_vect)
{
	// Unused
}

/*** end of file ***/

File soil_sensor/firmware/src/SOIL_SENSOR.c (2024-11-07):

/*
* @file SOIL_SENSOR.c
*
* @brief Soil Sensor main high-level library
*
*/

#include <stdio.h>
#include <stdbool.h>
#include <avr/wdt.h>

#include "DataTypes.h"
#include "ADC_atmega328p.h"
#include "NRF_lib.h"
#include "THINGS_lib.h"
#include "SOIL_SENSOR.h"

// Set to apply a an offset at battery measurement, clear otherwise
#define DEBUG_APPLY_VCC_OFFSET 1
// Set to round the ADC raw values, clear otherwise
#define DEBUG_SOIL_ADC_ROUND 1

// Data types
typedef enum
{
	SOIL_CHANNEL_1 = 1,
	SOIL_CHANNEL_2 = 2,
	SOIL_CHANNEL_3 = 3,
	SOIL_CHANNEL_4 = 4,
	
} Channel_t;

// Static variables
static uint8_t g_cycles = 0;
static uint16_t debug_batt_adc_raw = 0;
static double debug_batt_adc_volt = 0;
static uint16_t debug_soil_raw_1 = 0;
static uint16_t debug_soil_raw_2 = 0;
static uint16_t debug_soil_raw_3 = 0;
static uint16_t debug_soil_raw_4 = 0;

// Static functions
static void handle_channel_state(Soil_channel_t *channel);
static void update_eeprom();
static void button_pressed();
static void button_long_press_actions();
static void get_battery_voltage();
static void get_soil_moisture();
static void start_excitation_signal();
static void stop_excitation_signal();

#if 0
static uint16_t get_raw_maximum_value(double batt_voltage);
static uint16_t get_raw_minimum_value(double batt_voltage);
#endif

#if DEBUG_MEASUREMENTS
static void debug_measurements(void);
#endif

/*!
* @brief Sensor's initializations
*/
void SOIL_SENSOR_init()
{

#ifdef DEBUG
	CONSOLE_init();
	CONSOLE_log("SYSTEM STARTUP ", 1);
#endif

#if 0
	// NRF Testing - This is a while(1) function
	NRF_TEST_transmitter();
#endif

	// Sensor init
	g_cycles = 0;
	g_soil_sensor = SOIL_SENSOR_ZERO;
	g_soil_sensor.id = atoi((const char *)STRINGIZE(UUID));
	
	// RF Address from symbol
	// uint8_t temp_add[5] = RF_ADDRESS;
	Rf_address_t temp_add = TESTING_NRF_ADDR_THING_SENSOR_1;
	memcpy(g_soil_sensor.address, temp_add, RF_ADDRESS_BYTES);
	
	// Global gateway RF address for Soil Sensors
	Rf_address_t temp_add_gw = NRF_ADDRESS_GATEWAY_2_ENV_SENSORS;
	memcpy(g_soil_sensor.address_gw, temp_add_gw, RF_ADDRESS_BYTES);
		
	// g_soil_sensor.clock = g_time_epoch_y2k;
	g_soil_sensor.packet_id_tx = INVALID_PACKET_ID;
	
	// TODO: EEPROM
	//g_soil_sensor = SOIL_SENSOR_DEFAULT;
	//EEPROM_init_soil_sensor(&g_soil_sensor, EE_SOIL_SENSOR_DEFAULT);	
	
	// Initialize NRF lib
	NRF_init(TYPE_SOIL_SENSOR, g_soil_sensor.address_gw, g_soil_sensor.address);
}

/*!
* @brief Sensor's power-up
*/
void SOIL_SENSOR_power_up()
{
	// NOTE: Button and soil clock 1 share the same pin. Use as soil clock from now on
	INT_1_DISABLE;
	
	// Turn on ADC
	ADC_enable();
	// Turn on RF module
	NRF_power_on();
	
	// Button
	button_pressed();

	// Initialize soil clock 1 to be used for measurements
	SOIL_CLK_1_INIT;
	
	// Increase cycles
	g_cycles++;
}

/*!
* @brief Sensor's power-down
*/
void SOIL_SENSOR_power_down()
{
	if (g_cycles >= SOIL_SENSOR_MEASUREMENT_CYCLES || g_soil_sensor.is_active)
	{
		// Clear cycles
		g_cycles = 0;
	}
	
	// IMPORTANT NOTE: In case a retransmission may take place, consider re-sending the "previous" measurement with a flag in the packet.
	
	// Clear ALL measurements
	g_soil_sensor.battery_mv = 0;
	g_soil_sensor.channel_1.measurement = g_soil_sensor.channel_2.measurement = g_soil_sensor.channel_3.measurement = g_soil_sensor.channel_4.measurement = 0;
	
	// NOTE: Button and soil clock 1 share the same pin. Use as a button from now on
	SOIL_CLK_1_INIT; // TEST
	INT_1_ENABLE;
	
	// Turn off ADC
	ADC_disable();
	// Turn off RF module
	NRF_power_off();
	
	_delay_ms(1); // TBC if this is required
}

/*!
* @brief Sensor's measurements
*/
void SOIL_SENSOR_measurements()
{
	
#if (DEBUG_MEASUREMENTS)
	while (1) 
	{
#else		
		if (g_cycles < SOIL_SENSOR_MEASUREMENT_CYCLES && !g_soil_sensor.is_active)
		{
			return;
		}

#endif
		// Get battery voltage
		ADC_init(ADC_VREF_1V1);
		get_battery_voltage();

		// Get soil moisture
		start_excitation_signal();
		_delay_ms(SOIL_SENSOR_DELAY_EXCITATION_SIGNAL_MS);
		ADC_init(ADC_VREF_AVCC);
		get_soil_moisture();
		stop_excitation_signal();

#if (DEBUG_MEASUREMENTS)
		// Debug measurements
		debug_measurements();
		
		_delay_ms(DEBUG_MEASUREMENTS_DELAY_MS);
		wdt_reset();
	}
#endif

}

/*!
* @brief Sensor's tasks
*/
void SOIL_SENSOR_tasks()
{
	// NOTE: To handle the state of a channel, a measurement SHOULD take place just before.
	
	// Handle states
	handle_channel_state(&g_soil_sensor.channel_1);
	handle_channel_state(&g_soil_sensor.channel_2);
	handle_channel_state(&g_soil_sensor.channel_3);
	handle_channel_state(&g_soil_sensor.channel_4);
	
	// Update Sensor's active state. 
	g_soil_sensor.is_active = g_soil_sensor.channel_1.active | g_soil_sensor.channel_2.active | g_soil_sensor.channel_3.active | g_soil_sensor.channel_4.active;
}

/*!
* @brief Sensor's connection within network
*/
void SOIL_SENSOR_connection()
{
	NRF_LIB_Connect_res_t res = NRF_LIB_CONNECT_ERROR;
	
	// Connect Interval: 10 [sec]
	// Measurement Interval: 60 [sec]
	
	// Connect with gateway	
	res = NRF_connect_tx(g_soil_sensor.id, TYPE_SOIL_SENSOR);
	
	switch (res)
	{
		case NRF_LIB_CONNECT_SUCCESS:
			// Success
			g_soil_sensor.packet_id_tx = g_soil_sensor.packet_id_rx;
			
			// Update EEPROM
			update_eeprom();
			
			break;
			
		case NRF_LIB_CONNECT_SUCCESS_TX_ERROR_ACK:
			// Success, ACK Error
			g_soil_sensor.packet_id_tx = g_soil_sensor.packet_id_rx; // TBC
			break;
		
		case NRF_LIB_CONNECT_ERROR:
			break;
			
		default:
			break;
	}	
}

/************************************************************************************
******************************** Static functions ***********************************
************************************************************************************/

// Handle channel state
void handle_channel_state(Soil_channel_t *channel)
{
	// NOTE: The measurement here is supposed to be NEW (i.e. from this cycle)
	
	// TODO: Needs update to cover all cases, e.g. automation, timer, manual. Enable/disable, active state, force active state,... See word document.
	
	// Check if channel is enable for automation
	if (!channel->enabled)
	{
		channel->active = 0;
		return;
	}
	
	// Active state
	if (channel->active)
	{
		// Check stop condition
		if (channel->measurement - channel->measurement_prev <= 0 || channel->measurement >= channel->active)
		{
			channel->active = 0;
		}
		// Save last measurement
		channel->measurement_prev = channel->measurement;
	}
	
	// Inactive state - Check start condition
	if (channel->measurement <= channel->threshold_low)
	{
		// Save last measurement
		channel->measurement_prev = channel->measurement;
		// Set active
		channel->active = 1;
	}
}

// Updates EEPROM values
static void update_eeprom()
{
	
	if (!g_soil_sensor.sw_change)
	{
		return;
	}
	
	// TODO: EEPROM
	
	// EEPROM updated successfully
	g_soil_sensor.sw_change = 0;
	
}
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

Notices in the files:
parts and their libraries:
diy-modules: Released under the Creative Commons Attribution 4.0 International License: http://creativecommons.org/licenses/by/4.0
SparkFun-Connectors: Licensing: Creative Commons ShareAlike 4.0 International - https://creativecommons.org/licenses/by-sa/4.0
